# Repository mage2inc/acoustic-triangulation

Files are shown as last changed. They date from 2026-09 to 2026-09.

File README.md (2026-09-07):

# 🔊 acoustic-triangulation

> **DIY ShotSpotter for your property.** GPS-synchronized microphone nodes triangulate loud transients (gunshots, backfires, whatever goes boom) and pin the source on a map — no cloud, no subscription, ~$230 in parts.

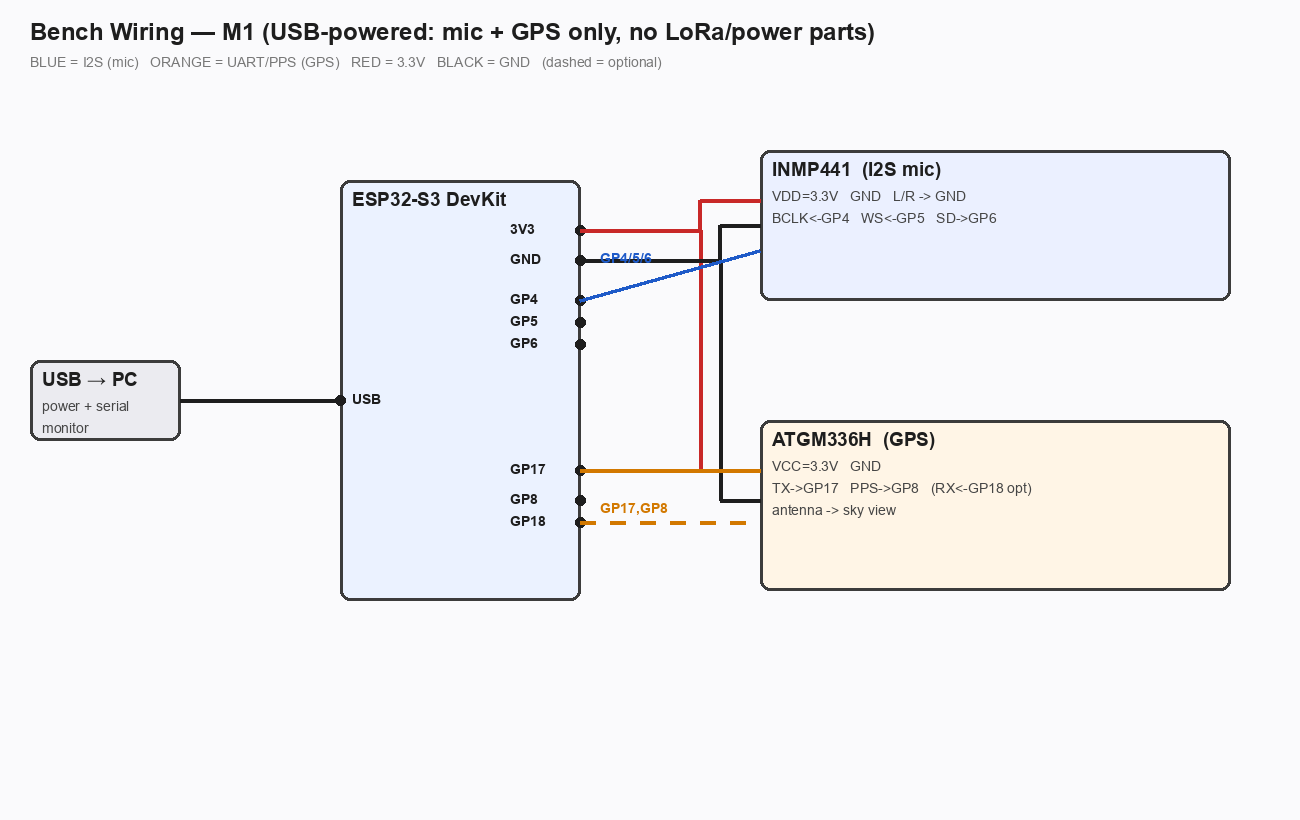
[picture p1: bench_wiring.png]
bench wiring


---

## How it works

Four solar-powered sensor nodes sit at the corners of the property. A fifth node lives indoors, doubles as the LoRa gateway, and feeds a Raspberry Pi.

When something loud happens, every node that hears it records the exact microsecond of arrival — disciplined to GPS PPS (the 1-pulse-per-second signal), which gives all nodes a common timebase accurate to <1 µs for free. Each node fires off a tiny 20-byte LoRa packet:

```
{ node_id, lat, lon, onset_time_µs, amplitude, classification }
```

The Pi collects the packets, computes **Time Difference of Arrival (TDoA)** across the nodes, and solves for the source location. Result: a dot on a Leaflet/OpenStreetMap web map, updated in real time.

**Expected accuracy:** 5–15 m. Dominated by GPS position error and node geometry, not timing.

---

## Why GPS PPS and not NTP / LoRa timing?

Sound travels ~34 cm per millisecond. NTP is good to ~10 ms → **3.4 m of timing error per ms**. LoRa is even slower and jittery. GPS PPS is <1 µs → sub-centimeter timing contribution. It's the only viable approach for outdoor acoustic TDoA at this scale.

LoRa is used **only** to ship the tiny detection report after the fact. It has nothing to do with timing.

---

## Hardware variants

Two board variants exist. **Only v2 has been built and tested on the bench.**

| Variant | Radio | PCB | Status |
|---|---|---|---|
| **v2 — RYLR689** | LLCC68 (SPI bare module) | Hand-wired breadboard / CNC milled | ✅ Tested — bench sync confirmed |
| **v3 — XL1276-P01** | SX1276 (SPI castellation) | JLCPCB 2-layer FR4, 56×53 mm | ⚠️ **UNTESTED** — gerbers ready, not yet ordered |

v3 uses the same ESP32-S3-Zero and GPS/mic modules as v2. The SX1276 needs 3 fewer GPIO pins (no BUSY, no RF-switch lines) and is meant to be manufactured, not hand-wired.

> **If you're building now, use v2 (RYLR689).** See [BOM.md](BOM.md) and [WIRING.md](WIRING.md).
> v3 PCB files and BOM are in this repo but have not been ordered or soldered yet.

---

### v2 field node ×4 (RYLR689 — active variant)

| Part | ~$ |
|---|---|
| ESP32-S3-Zero (dual-core LX7, 2 MB PSRAM) | 4.50 |
| INMP441 I²S MEMS microphone | 1.80 |
| RYLR689 LLCC68 915 MHz LoRa (SPI) | 9.00 |
| ATGM336H GPS with PPS pin | 4.50 |
| 6 V / 5 W solar panel | 8.00 |
| CN3791 MPPT solar charger | 3.00 |
| 18650 Li-ion cell + holder | 5.00 |
| IP65 ABS enclosure | 4.50 |
| Acoustic vent (PTFE membrane) | 1.50 |
| Misc wire / JST / mount | 5.00 |
| **Per node** | **~$47** |

### Office node ×1 (mains, USB-powered from Pi)

Same sensor stack, no solar/battery. Active external GPS antenna for indoor sky-view. Also acts as the LoRa gateway.

### Base station

Raspberry Pi (any model with USB) + the office node + a browser. No cloud. No API key. Leaflet + OpenStreetMap.

**Full BOM with sourcing notes and buy links → [BOM.md](BOM.md)**

**v3 (SX1276 / manufactured PCB) BOM and fab guide → [BOM_sx1276.md](BOM_sx1276.md) · [pcb/fab_guide_sx1276.md](pcb/fab_guide_sx1276.md)**

**Detailed power budget, solar sizing, and low-power DS3231 holdover variant → [POWER.md](POWER.md)**

---

## Repo layout

```
firmware/          PlatformIO project — ESP32-S3 node firmware
  src/
    acoustic_core.h   timing engine (GPS-PPS + I²S DMA ring + onset detector)
    node_config.h     pin map + node ID (edit per node)
    main_stageN.cpp   staged build environments (mic → GPS → onset → full node)
  platformio.ini      default env = SX1276; add -D LORA_MOD_LLCC68 for RYLR689

base/
  base_station.py   LoRa RX → TDoA solver → Leaflet map (Flask)
  test_solver.py    unit tests for the multilateration math
  requirements.txt

pcb/                       ⚠️ v3 SX1276 PCB — UNTESTED, not yet ordered
  gen_pcb_sx1276.py        Gerber generator (Python, no KiCad needed)
  gen_pcb.py               v2.2 RYLR689 CNC preview (reference only)
  out_sx1276/              Ready-to-upload gerbers for JLCPCB
  fab_guide_sx1276.md      JLCPCB ordering steps + pricing

BOM.md             v2 RYLR689 bill of materials (tested)
BOM_sx1276.md      v3 SX1276 bill of materials ⚠️ untested
POWER.md           Power budget, solar sizing, battery autonomy, DS3231 holdover
WIRING.md          Pin-by-pin wiring for both variants
POC.md             Proof-of-concept plan (USB-powered bench test first)
NODE_FIRMWARE_DESIGN.md  Detailed firmware architecture
FIELD_TEST.md      Field deployment checklist
```

---

## Firmware quick-start

Requires **PlatformIO** and the **pioarduino** platform (Arduino core 3.x — the new `i2s_std.h` driver needs it; stock espressif32 core 2.x won't compile).

```bash
cd firmware

# Stage 1 — mic level meter (sanity check before wiring everything)
pio run -e stage1 -t upload -t monitor

# Stage 2 — GPS lock + PPS pulse counter
pio run -e stage2 -t upload -t monitor

# Stage 3 — onset detection + PPS timestamp
pio run -e stage3 -t upload -t monitor

# Stage 4 — full node (onset → LoRa TX)
pio run -e stage4 -t upload -t monitor

# Stage 5 — base RX + sync check (run on office node / DevKit)
pio run -e stage5 -t upload -t monitor
```

Edit `src/node_config.h` to set `NODE_ID` (0–4) and verify pin assignments before flashing each node.

> **Gotcha:** the S3FH4R2 chip has 4 MB flash but the default board profile assumes 8 MB → bootloop. `platformio.ini` already sets `board_upload.flash_size=4MB` and `board_build.flash_size=4MB`. Don't remove those lines.

---

## Base station quick-start

```bash
cd base
pip install -r requirements.txt

# Sanity-check the solver math (runs without hardware)
python test_solver.py

# Start the gateway + map server
# Office node must be plugged in via USB
python base_station.py --port /dev/ttyUSB0 --map-port 5000
```

Open `http://localhost:5000` — events appear as pins on the map as they arrive.

---

## Node placement

Property is ~52 m × 155 m (long and narrow). **Do not line nodes along the centerline** — colinear geometry kills cross-width accuracy. Stagger them in a zigzag/W pattern, pushing to the extreme corners, so you get perpendicular baselines in both axes.

```
N1 ──────────────────── N2
 \                      /
  \    (office node)   /
   N5                 /
  /                  /
N3 ──────────────────── N4
```

Every node hears every event on this lot → over-determined system → ambiguity rejection works.

---

## Accuracy

| Error source | Contribution |
|---|---|
| GPS PPS timing | <1 µs → <0.3 mm |
| GPS position error (single-point) | ~2–5 m |
| Node geometry (52 m narrow axis) | limits cross-width to a few meters |
| Speed of sound variation (temp/wind) | ~1–3 m in practice |
| **Combined** | **~5–15 m** |

The timing is not the limiter. Node position error and geometry are. Sub-meter accuracy requires tape-survey + hardcoded positions.

---

## Cost

| Group | Cost |
|---|---|
| 4 solar field nodes | ~$189 |
| 1 mains office node | ~$28 |
| Base (Pi on hand) + microSD | ~$6 |
| Bench dev kit | ~$8 |
| **Total** | **~$231** |

Commercial ShotSpotter: $50,000–$100,000 per square mile. Just saying.

---

## License

MIT

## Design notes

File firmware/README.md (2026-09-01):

# Node firmware

ESP32-S3 node firmware for the acoustic triangulation array, built in testable
stages (see `../POC.md` for the milestone plan). Arduino framework via
**PlatformIO**.

## Toolchain
- Install PlatformIO (VS Code extension or `pip install platformio`).
- Board target: `esp32-s3-devkitc-1` (works for the DevKitC-1 *and* the
  ESP32-S3-Zero — same chip). Serial is native USB (CDC).

## Build & flash one stage
```
pio run -e stage1 -t upload -t monitor      # I2S mic level meter
pio run -e stage2 -t upload -t monitor      # GPS + PPS timestamp
```
(Each stage is one file selected by `build_src_filter` in `platformio.ini`.)

## Stages
| Stage | File | Proves | Pass criteria |
|---|---|---|---|
| 1 | `stage1_i2s_mic.cpp` | mic captures audio | tap/clap moves the RMS bar |
| 2 | `stage2_gps_pps.cpp` | PPS disciplines a µs clock | `interval` ≈ **1000000 µs** after fix |
| 3 | *(next)* | onset → GPS-time timestamp | clap prints a precise UTC-referenced µs |
| 4 | *(next)* | LoRa report | base prints the packet |
| 5 | *(next)* | **2-node PPS sync (M2)** | Δt ≈ Δdistance ÷ 343 m/s |
| 6 | *(Pi)* | multilaterate + Leaflet map | dot lands within a few m |

## Pin map
All pins in `src/node_config.h`. Set `NODE_ID` per node (1..5).

## Notes
- **Stage 2 needs sky view** — first GPS fix can take minutes; PPS typically
  starts after the first fix.
- If Stage 1 reads flat/zero: check `L/R`→GND and the SD/BCLK/WS wiring; the
  INMP441 drives the LEFT slot.
- Libs (`RadioLib`, `TinyGPSPlus`) auto-install on first build.

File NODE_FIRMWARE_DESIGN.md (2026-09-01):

# Acoustic Triangulation — Node Firmware Design

Two-tier (lazy) firmware for a solar-powered sensor node in a distributed
loud-noise/gunshot triangulation network. Nodes detect a loud transient,
precisely timestamp its **onset** against GPS PPS, classify it, and send a tiny
report over LoRa. The base station collects reports from ≥3 nodes and solves
for the source location (TDoA multilateration) on a Leaflet/OSM map.

**Design targets**
- Sub-meter localization on a 52 m × 155 m property.
- Runs continuously on solar; average current near the low-power floor.
- Rejects false alarms (thunder, car doors, dogs) via classification.

---

## 1. Hardware per node

| Block | Part | Interface | Notes |
|---|---|---|---|
| MCU | ESP32-S3 (N16R8, 16 MB flash / 8 MB PSRAM) | — | dual-core; wake-to-classify |
| Mic | INMP441 (I²S MEMS) | I²S | continuous DMA capture |
| Radio | Ra-01 / SX1278 (433 MHz LoRa) | SPI + DIO0 IRQ | tiny report packets |
| Time/pos | ATGM336H (GPS+BDS timing) | UART (NMEA) + **PPS** | PPS is the whole ballgame |
| Power | 5–6 W panel + 2× 18650 + CN3791/TP4056 | — | see power notes |

### Pin map — Waveshare ESP32-S3-Zero (final)
Board breaks out ~24 GPIO (GP1–18, 38–42, 45). Map avoids strapping pins
(0/3/45/46), USB console (43/44 = UART0), USB D±(19/20), and GP21 (onboard WS2812).
All signals are 3.3 V — no level shifting.
```
INMP441 (I²S):   BCLK=GP4    WS=GP5     SD=GP6         (L/R -> GND = left channel)
SX1278 (SPI):    SCK=GP12    MISO=GP13  MOSI=GP11
                 CS=GP10     RST=GP14   DIO0=GP9 (IRQ)
ATGM336H:        GPS_TX->GP17 (ESP RX)  ESP_TX->GP18 (GPS RX, optional)
                 PPS=GP8     (interrupt-capable, non-strapping — CRITICAL)
Status LED:      GP21 (onboard WS2812, no header pin)
Free for later:  GP1-3, 7, 15, 16, 38-42, 45  (SD logging, 2nd mic, PIR, ...)
```
Power: Ra-01 and ATGM336H on **3V3** (Ra-01 is NOT 5 V tolerant); board 5V pad
feeds the regulator from the solar/battery supply.

---

## 2. The crux: GPS-PPS timekeeping

Everything depends on all nodes sharing one clock to < ~1 ms. We get that from
the GPS **PPS** (pulse-per-second) edge, which is aligned across all GPS
receivers on Earth to < 1 µs. We never use LoRa for timing.

### Clock model
Maintain a mapping between the **local high-res timer** (`esp_timer`, 1 µs, or the
CPU cycle counter) and **GPS UTC**:

- On every **PPS rising edge** (hardware ISR), latch the local timer:
  `t_pps_local = now_us()`. The NMEA sentence that follows tells you which UTC
  second that PPS marked → keep `utc_at_pps`.
- Measure `ticks_between_pps = t_pps_local[n] - t_pps_local[n-1]`. Nominal is
  1 000 000 µs; the deviation is your local oscillator error (ppm). Use it to
  scale interpolation (optional but improves accuracy / holdover).

### Sample → GPS time
I²S samples arrive via DMA at a fixed rate `Fs` (e.g., 16 kHz). To timestamp a
specific **sample index**:

- On each DMA "buffer complete" ISR, latch `now_us()` and the running
  `sample_count`. This anchors `sample_index ↔ local_time`.
- For any sample: `local_time = anchor_time + (sample_index - anchor_index)/Fs`.
- Then convert local_time → GPS time via the PPS mapping:
  `T_gps = utc_at_pps + (local_time - t_pps_local) * (1e6 / ticks_between_pps)`.

**Achievable precision:** limited by `Fs` (16 kHz = 62.5 µs/sample; interpolate
the threshold crossing for sub-sample), ISR jitter (~µs), and PPS jitter (~µs).
Realistically **~50–200 µs → ~2–7 cm of ranging error**. Timing is *not* your
accuracy limiter; node geometry and echoes are.

> Keep the I²S DMA ring buffer running even in the low-power tier, so the
> onset sample already exists in memory when the threshold trips.

---

## 3. Audio ring buffer

A continuous circular buffer of recent audio in RAM.

- 16 kHz × 16-bit × 1.0 s = **32 KB** (trivial; with PSRAM keep several seconds).
- Purpose: **pre-trigger history.** The energy threshold trips slightly *after*
  the true onset; the pre-roll lets you look back and find the real onset edge.
- Window captured per event: ~50 ms pre-trigger + ~250 ms post-trigger.

```
      ring buffer (circular, always filling via DMA)
  ...[....pre-roll....][ONSET][....decay....].... write ptr ->
                         ^ found by looking back from trigger point
```

---

## 4. Two-tier state machine (the "lazy" design)

```
        ┌──────────────────────────────────────────────┐
        │  STATE_LISTEN  (CPU 80 MHz, low power)         │
        │  • I²S DMA -> ring buffer (always)             │
        │  • PPS ISR keeps clock disciplined             │
        │  • per-DMA-buffer: cheap energy/peak check     │
        │  • LoRa idle (sleep or RX)                     │
        └───────────────┬──────────────────────────────┘
                        │ energy > THRESHOLD
                        v
        ┌──────────────────────────────────────────────┐
        │  STATE_EVENT   (CPU 240 MHz, brief burst)      │
        │  1. snapshot ring-buffer window                │
        │  2. find precise onset sample (rising edge)    │
        │  3. T_onset = sample->GPS time  (Sec.2)        │
        │  4. classify window (Sec.5)                    │
        │  5. if of-interest: build + TX LoRa report     │
        │  6. refractory dead-time (~700 ms) to ignore   │
        │     echoes, then -> STATE_LISTEN               │
        └──────────────────────────────────────────────┘
```

Because loud events are rare (seconds/day), you sit in STATE_LISTEN ~99.9 % of
the time → average current ≈ the low tier, while STATE_EVENT gives you full
S3-class classification only when it matters.

> **Power reality:** this shaves the *CPU* portion. GPS (~30–50 mA continuous)
> is the dominant draw and is unchanged — it sets the floor.

---

## 5. Onset detection & classification

### Onset (timing-critical)
- Trigger: short-window RMS/energy over a sliding ~2–5 ms window exceeds an
  adaptive threshold (threshold = k × rolling noise floor).
- Precise onset: from the trigger point, walk **backward** in the ring buffer to
  the last sample below a lower fraction of the peak → that's the onset edge.
  Optionally linear-interpolate the exact crossing for sub-sample time.

### Classification (false-alarm rejection)
Compute cheap features over the captured window and score impulsive-vs-not:

| Feature | Gunshot-like | Rejects |
|---|---|---|
| Rise time (10→90 % of peak) | very short (< 1–2 ms) | slow → thunder, engine |
| Total duration | short (tens of ms + echoes) | long → rumble, music |
| Peak amplitude | high | low → distant/ambient |
| Spectral flatness / centroid | broadband, high | tonal → alarms, voices |
| Zero-crossing rate | high | low → thuds |
| (optional) crest factor | high | compressed sounds |

Start with a simple weighted-threshold rule; upgrade to a tiny TinyML model
later if needed. Emit a `class` id + `confidence`.

---

## 6. LoRa transmit — collision avoidance (important)

Every node hears the same gunshot within ~450 ms, so **all nodes want to
transmit at nearly the same instant** → LoRa collisions that could wipe out the
event. Two rules fix this:

1. **The timestamp is in the payload, not the RX time** — so *when* the packet
   arrives at the base doesn't matter. We can freely delay/jitter TX.
2. **Per-node staggered backoff:** after capturing `T_onset`, wait
   `backoff = node_id × 60 ms + small_random` before transmitting. Nodes'
   packets are then spread out and don't collide. Optionally listen-before-talk.

Also: 2–3 quick repeats per report (LoRa is lossy), deduped at the base by
`(node_id, seq)`.

### Packet format (~20 bytes — MOBILE nodes send their own position)
```
byte  field
0     node_id                (1)
1-2   seq                    (2)   for dedupe / repeats
3-7   onset_time_us          (5)   40-bit: µs-of-hour (or since GPS epoch tick)
8-11  latitude               (4)   int32, 1e-7 deg  (~1 cm resolution)
12-15 longitude              (4)   int32, 1e-7 deg
16-17 peak_amp               (2)
18    class_id               (1)
19    confidence             (1)
+ LoRa hardware CRC
```
> **Nodes are static during operation but self-locating.** At deploy each node
> takes a GPS position lock and **averages it while stationary** (pulls error to
> ~1–2 m), stores it, and includes it in every report. So nodes are plug-and-play
> and handle redeployment automatically — no manual survey, no base lookup table.
> GPS keeps running afterward purely for PPS timing.

**LoRa params:** 433 MHz, SF7–SF9 / 125 kHz (short range, low airtime), CRC on,
explicit header.

---

## 7. Concurrency layout (dual-core)

```
Core 0 (real-time, never blocks):
  • I²S DMA buffer-done ISR: latch time anchor, run energy check,
    set event flag on trigger
  • PPS ISR: latch t_pps_local, update clock mapping

Core 1 (app):
  • GPS UART / NMEA parse -> utc_at_pps, node health
  • on event flag: snapshot window, onset, classify, backoff, LoRa TX
  • status LED / housekeeping
```

Keep ISRs tiny (latch + flag). Do all heavy work (classify, TX) on Core 1.

---

## 8. Main-loop pseudocode

```c
void setup() {
  clock_set(80_MHz);
  i2s_start_dma(Fs=16000, ring_buffer);      // runs forever
  attach_isr(PPS_PIN, on_pps_edge);          // Core 0
  attach_i2s_done_isr(on_dma_buffer);        // Core 0
  gps_uart_begin();                          // Core 1
  lora_begin(433E6, SF8, 125E3);
  state = LISTEN;
}

// ---- Core 0 ISRs ----
void on_pps_edge() {
  uint64_t t = now_us();
  ticks_between_pps = t - t_pps_local;
  t_pps_local = t;
  pps_seen = true;                            // NMEA parser fills utc_at_pps
}

void on_dma_buffer(int16_t* buf, int n) {
  anchor_time = now_us(); anchor_index = (sample_count += n);
  float e = energy(buf, n);
  noise_floor = 0.999f*noise_floor + 0.001f*e;    // slow adaptive
  if (state == LISTEN && e > K * noise_floor) {
    trigger_index = sample_count;
    event_flag = true;                            // hand to Core 1
  }
}

// ---- Core 1 ----
void loop() {
  gps_service();                              // parse NMEA -> utc_at_pps
  if (event_flag && state == LISTEN) {
    state = EVENT; clock_set(240_MHz);
    Window w = snapshot_ring(trigger_index, PRE=50ms, POST=250ms);
    size_t onset = find_onset(w);
    uint64_t T_onset = sample_to_gps_time(onset);   // Sec.2
    Class c = classify(w);                          // Sec.5
    if (c.of_interest) {
      delay(node_id*60 + rand()%40);                // Sec.6 backoff
      lora_send(pack(node_id, seq++, T_onset, w.peak, c));
    }
    delay(REFRACTORY_700ms);                        // ignore echoes
    clock_set(80_MHz); state = LISTEN; event_flag = false;
  }
}
```

---

## 9. Base station (outline — separate doc later)

Runs on a Raspberry Pi + one Ra-01 gateway.

1. **Ingest**: receive LoRa reports, dedupe `(node_id, seq)`.
2. **Correlate**: group reports whose `onset_time_us` fall within ~450 ms
   (max propagation across the property) into one *event*.
3. **Solve**: TDoA multilateration using the **GPS-averaged node positions each
   node self-reports** + onset times. Least-squares / Levenberg–Marquardt seeded
   by a coarse grid search; output lat/lon + residual. Need ≥3 nodes; 4+ rejects
   the mirror ambiguity. Accuracy bounded by node position error: ~**2–5 m** with
   GPS averaging (or sub-meter if you also tape-survey and hardcode positions).
4. **Serve**: Leaflet + OpenStreetMap web page (WebSocket live) showing nodes,
   the computed source, and an error circle. Log every event to SQLite.

---

## 10. Tuning knobs & open items

- **Fs**: 16 kHz is plenty for onset timing + basic classify; 8 kHz saves power,
  32 kHz sharpens timing. Trade against CPU/power.
- **K (threshold)** and **noise-floor time constant**: field-tune to your
  ambient; too low = constant wakes (burns the lazy savings), too high = misses.
- **Refractory time**: long enough to swallow echoes off house/trees, short
  enough not to miss a real second event.
- **Node survey**: measure each node's lat/lon once (tape-measure to a local
  grid, or average a GPS fix for minutes). Store in the base's table. This is
  what turns ~3 m GPS error into cm-level position → sub-meter fixes.
- **Node layout**: stagger across the 52 m width; never colinear.
- **Power**: verify average current on the bench, then size panel/battery for
  worst-case cloudy days (target ≥2–3 days autonomy). GPS is the floor —
  consider GPS duty-cycling + a TCXO holdover only if you must go lower.
- **LoRa duty cycle / region**: mind 433 MHz regional limits; reports are tiny
  so this is easy to stay under.

---

---

## Appendix A — Low-Power Variant (GPS duty-cycle + DS3231 holdover)

**Optional.** The default design runs GPS continuously (~30 mA = half the node
budget). This variant nearly halves node draw for nodes that need it. **Skip it
for solar nodes** (already power-positive); use it only for:
- battery-only nodes (no solar) — halving draw ~doubles runtime,
- heavily shaded sites where the 5 W panel can't keep up,
- shrinking to a smaller panel/battery to cut cost/size.

### Idea
A bare ESP32 crystal drifts too fast — and drifts with *outdoor temperature* —
so you can't coast without GPS. Add a **DS3231 (TCXO RTC, ±2 ppm, temperature-
stable)**. Then you can turn the GPS OFF and hold time on the TCXO between brief
re-syncs.

### Added hardware
- **DS3231 + AT24C32 module** (~$2, I²C). TCXO holdover + EEPROM for node
  config/ID/optional surveyed position.
- **High-side P-MOSFET** (or the GPS module's standby pin) to gate GPS power.

### Extra pins (from the free set)
```
DS3231 I²C:   SDA=GP1   SCL=GP2
DS3231 32kHz: 32K -> GP7   (optional: TCXO reference into a counter)
GPS enable:   GP15 -> MOSFET gate (cut GPS VCC when sleeping)
```

### How it works
1. **Sync phase (GPS on):** get position fix (average once, store in EEPROM) +
   discipline the ESP32 high-res timer against PPS; measure the TCXO's exact
   offset. Establish `timer_ticks ↔ GPS_time` and the ppm correction.
2. **Holdover phase (GPS off):** run the ESP32 fast timer, corrected by the
   DS3231 32.768 kHz TCXO reference (temperature-stable). Onset timestamps use
   this held timebase. Coast for the re-sync interval.
3. **Re-sync:** every ~2–3 min pulse GPS on (~2 s hot-start), re-lock PPS,
   re-measure the timer offset, GPS off again.

### Budget & timing
- GPS: ~30 mA continuous → **~1 mA average** (~1.6 % duty) + ~0.2 mA DS3231.
- **Node ~58 mA → ~28 mA** (roughly halved).
- Timing: ±2 ppm over a 3-min holdover → worst-case ~0.7 ms cross-node relative
  drift → **~0.25 m ranging error** — inside the 2–5 m target. Tighten the
  re-sync interval if you want margin.

### Cost / risk
Real firmware complexity: holdover discipline math, GPS on/off sequencing, and
you MUST field-validate cross-node timing holds (compare a known common event).
Not worth it unless power-starved. Keep the DS3231 as a stocked option.

---

*Status: design. Next: exact BOM w/ links, then implement node firmware
(I²S + PPS timestamp first, then classify, then LoRa), then the base solver+map.*

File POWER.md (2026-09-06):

# Power Budget — Acoustic Triangulation Nodes

## Field node current draw (continuous, 3.3 V rail)

| Subsystem | Mode | Current |
|---|---|---|
| ESP32-S3 (dual-core @ 80 MHz, STATE_LISTEN) | always-on | ~25 mA |
| ATGM336H GPS (lock acquired, PPS running) | always-on | ~28–35 mA |
| INMP441 MEMS mic (I²S DMA, always capturing) | always-on | ~1.4 mA |
| RYLR689 LoRa (idle / Tx burst avg ~0.1% duty) | mostly sleep | ~1–2 mA |
| **Total (typical)** | | **~58 mA** |

> **GPS is the dominant draw** — it stays on 100% of the time because it provides
> both the position AND the PPS timebase. Duty-cycling it saves ~15 mA average
> but requires a DS3231 TCXO holdover and adds firmware complexity (see Appendix A).

During `STATE_EVENT` (onset detected, classify + LoRa Tx):
- CPU briefly runs @ 240 MHz → +~50 mA for ~100–300 ms
- LoRa Tx @ +20 dBm → +~120 mA for ~50 ms
- Both are short bursts; average impact on daily energy is negligible (<0.5%)

**Average draw used for sizing: 58 mA @ 3.3 V = ~0.19 W**

---

## Daily energy

```
58 mA × 3.3 V × 24 h = 4.6 Wh/day
```

---

## Solar panel sizing

A 5 W / 6 V panel in a mid-latitude location with ~4 peak-sun-hours/day delivers:

```
5 W × 4 h × ~0.85 (MPPT efficiency) = ~17 Wh/day harvested
```

vs. **4.6 Wh/day needed** → **3.7× margin**. Covers cloudy stretches and charging
the battery simultaneously. Don't downsize the panel — the GPS is not negotiable.

| Panel | Cost | Verdict |
|---|---|---|
| 6 V 5 W (110 × 136 mm) | ~$8 | ✅ right-sized, use this |
| 6 V 2 W | ~$4 | ❌ marginal even in full sun |
| 12 V 10 W | ~$15 | overkill, also needs a different charger |

> **"10 W" panel gotcha:** a panel labeled 10 W doing 12 V × 0.166 A is really
> ~2 W. Always check Vop × Iop (the operating point), not the label.

---

## Battery sizing

| Config | Capacity | Autonomy (no sun) | Notes |
|---|---|---|---|
| 1× 18650 (2 500 mAh) | ~8.3 Wh | **~1.5 days** | lean / default BOM |
| 2× 18650 (5 000 mAh) | ~16.5 Wh | **~3.5 days** | +$4/node, recommended |
| 3× 18650 (7 500 mAh) | ~24.8 Wh | **~5 days** | +$8/node, comfortable margin |
| 1× 32700 LiFePO₄ (6 000 mAh) | ~19.8 Wh | **~4.2 days** | +$5/node, safer in hot enclosures |

Autonomy formula: `capacity_Wh / 4.6 Wh/day`

**Recommendation:** 2× 18650 in parallel (or 1× 32700 LiFePO₄ if the enclosure
gets hot). The system tolerates a node browning out and rejoining — a missed
detection just reduces fix quality slightly.

> ❌ **Never use a USB power bank.** They auto-cutoff at low draw (~58 mA triggers
> most power banks' "no load" protection). Use bare Li-ion cells with a 1S
> protection board, or protected cells.

---

## Power chain

```
6 V solar panel
    │
    ▼
CN3791 MPPT charger  ──── charges ──── 18650 cell (1S)
    │                                       │
    └─── (direct path when sun > load) ─────┘
                                            │
                                        Schottky diode
                                            │
                                    ESP32-S3-Zero 5V pad
                                            │
                                     onboard AMS1117 LDO
                                            │
                                           3V3 ──► GPS, mic, LoRa, ESP32
```

No separate buck-boost needed — the ESP32-S3-Zero's onboard LDO accepts 3.3–6 V
on the 5V pad and regulates to 3.3 V. The Schottky diode prevents USB-C and the
solar supply from fighting when you plug in for debugging.

---

## Appendix A: Low-power variant (DS3231 holdover)

Halves average current by duty-cycling the GPS. Only worthwhile on battery-only
or heavily shaded nodes.

### How it works

1. Node acquires GPS lock, pairs PPS, then gates off the GPS module.
2. A DS3231 TCXO RTC (±2 ppm) takes over as the time reference.
3. GPS wakes every ~3 minutes for a 2–5 s re-discipline pulse, then sleeps again.

### Error budget during holdover

```
Holdover gap: 3 min = 180 s
DS3231 drift: ±2 ppm
Max timing error: 180 s × 2×10⁻⁶ = 360 µs
Distance error: 360 µs × 343 m/s = ~0.12 m
```

Sub-meter — GPS position error (2–5 m) still dominates. The holdover approach is
timing-safe.

### Power savings

| Subsystem | Always-on | With holdover |
|---|---|---|
| GPS | ~30 mA | ~2 mA avg (30 mA × 5 s / 180 s) |
| DS3231 | 0 | ~0.2 mA |
| **Total** | **~58 mA** | **~30 mA** |

~48% reduction. Daily energy drops from 4.6 Wh to ~2.4 Wh → a 2 W panel and
1× 18650 are sufficient.

### Cost

| Part | ~$ |
|---|---|
| DS3231 RTC module (32 kHz + coin cell backup) | $1.50 |
| CR2032 coin cell | $0.50 |
| **Per node add-on** | **~$2** |

### When to use it

- Battery-only nodes (no solar) ✅
- Heavily shaded nodes where the 5 W panel can't fully recharge ✅
- Nodes that need to last a week between maintenance visits ✅
- Solar nodes in a sunny location ❌ (already power-positive, not worth the complexity)

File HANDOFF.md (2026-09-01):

# HANDOFF — Acoustic Triangulation (portable/uConsole continuation)

Self-contained project. Read `PROJECT_MEMORY.md` first (full context), then
`POC.md` (plan) and `firmware/README.md` (build).

## Where we are (hardware bring-up, verified on a MacBook)
- Board CONFIRMED: ESP32-S3, 4MB flash / 2MB PSRAM (S3FH4R2). `/dev/cu.usbmodem2101` on the Mac.
- Toolchain: PlatformIO + **pioarduino platform** (core 3.x) — set in `firmware/platformio.ini`.
  Also fixed: **4MB flash override** (board_upload.flash_size=4MB, partitions=default.csv).
- Pin map moved to the GP1..13 breadboard header (this board's GP14+/GP17/18 are solder pads).
  See `firmware/src/node_config.h`: I2S 4/5/6, GPS TX->GP1 / PPS->GP8, LoRa 12/13/11/10/9/RST=7.
- Stage 1 (mic): PASS — RMS/peak jump with sound.
- Stage 2 (GPS): GPS UART WIRED OK (NMEA chars climbing). sats=0 INDOORS (no fix yet).

## NEXT STEP (needs sky view — that's why we're going portable)
1. Plug the ESP32 into the uConsole. `pip install platformio` if needed.
2. `cd firmware && pio run -e stage2 -t upload -t monitor`  (port may be /dev/ttyACM0)
3. Take it OUTSIDE / by a window. Wait for `sats` to climb, get a fix, then PPS starts:
   confirm **`interval` locks to ~1000000 us**. That proves PPS/GP8 + the synchronized clock.
4. Then `pio run -e stage3 -t upload -t monitor`, clap -> prints a GPS-referenced timestamp = **M1 DONE**.
5. M2 (make-or-break): 2 nodes on stage4 + a base on stage5, clap between them,
   verify base prints `dt ~ Δdistance/343`.

## Notes for the uConsole
- Serial port is likely /dev/ttyACM0 (not cu.usbmodem). Add `--upload-port /dev/ttyACM0` or set `upload_port`/`monitor_port` in platformio.ini.
- First `pio run` downloads the toolchain (~few min).
- Base solver already validated (base/test_solver.py: 0.04m clean, ~2.8m realistic).

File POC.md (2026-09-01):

# Proof-of-Concept Plan (USB-powered, no solar/battery)

Validate the *risky* parts — GPS-PPS time-sync and TDoA — before investing in
the power hardware. POC kits become the real nodes later (just add the power
stack). Nothing wasted.

## POC BOM (per node, USB-powered)
| Item | ~$ |
|---|---|
| ESP32-S3-Zero | 4.50 |
| INMP441 I²S mic | 1.80 |
| Ra-01 SX1278 w/ spring antenna | 4.50 |
| ATGM336H GPS (PPS + antenna) | 4.50 |
| USB-C cable | 1.50 |
| **Per node** | **~$17** |

**Dropped for POC:** solar panel, CN3791, 18650 + holder, Schottky/cap
(buck-boost already dropped), enclosure, acoustic vent.

**Power during test:** USB wall adapter + outdoor extension, or a power bank with
an always-on/low-current mode (plain power banks auto-off at ~58 mA). GPS needs
sky-view → nodes at windows / outside during tests.

## Cost
4 node kits (~$68) + ESP32-S3-DevKitC-1 (~$8) + Pi/microSD (on hand) ≈ **~$76**
vs ~$209 full build. Power hardware deferred until M2 passes.

## Milestones
1. **M1 — 1 node (bench).** I²S capture → onset detect → GPS lock → PPS timestamp
   → LoRa packet to base. Proves the node pipeline end to end. *(1 kit + DevKit)*
2. **M2 — 2 nodes (make-or-break).** Known separation; clap/bang; verify both
   timestamp the SAME event and Δt ≈ (Δdistance ÷ 343 m/s). **If PPS sync holds
   here, the project works.** *(2 kits)*
3. **M3 — 4 nodes at corners.** Full triangulation + Leaflet map; check fixes land
   within a few meters of the real source. *(4 kits)*

## After POC
Once M2/M3 pass, add per node: 12 V ~5–6 W panel + CN3791 (matched to panel V) +
3× 18650 (parallel) + Schottky + cap + IP65 box + acoustic vent. See BOM.md.

## Build order for firmware (do M1 first)
1. I²S continuous capture into a ring buffer (verify clean audio).
2. GPS NMEA parse + **PPS interrupt → discipline µs timer** (the crux).
3. Onset detect + sample→GPS-time timestamp.
4. LoRa packet {node_id, onset_us, lat, lon, amp} → base.
5. Base: collect, correlate, multilaterate, Leaflet map.

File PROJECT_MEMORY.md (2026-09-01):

---
name: project_acoustic_triangulation
description: Distributed loud-noise/gunshot TDoA triangulation network — MCU+mic+GPS+LoRa field nodes report to a base station that multilaterates and plots the source on a web map
metadata: 
  node_type: memory
  type: project
  originSessionId: 24c60d79-960e-49b6-99aa-ac79bfe38bc8
---

DIY ShotSpotter-style acoustic sensor network. Many field units (microcontroller + microphone + GPS + LoRa) detect loud transients, report to a base station over LoRa; base triangulates the source and plots it on a map with an API.

**Core method: TDoA multilateration.** Each node timestamps sound *arrival*; differences in arrival times × speed of sound (343 m/s) + known GPS node positions → solve for source. Need ≥3 nodes hearing an event for a 2D fix, 4+ for robustness/ambiguity rejection.

**THE make-or-break design point: time sync via GPS PPS, NOT LoRa.** Sound travels ~34 cm/ms; LoRa is far too slow/jittery for timing. Every node disciplines its µs clock to the GPS **PPS (pulse-per-second, <1µs)** signal → common timebase for free. LoRa is used ONLY to send a tiny detection report `{node_id, lat, lon, onset_time_µs, amplitude}` (~20 bytes) after a trigger — never for timing or audio.

**Hardware recommended:**
- Node: **LilyGO T-Beam** (ESP32 + NEO-M8N GPS + SX1262 LoRa + 18650 holder, all on one board) — add a mic, break out GPS PPS pin.
- Mic: I²C mic is a poor fit (slow sound-level sensor). Prefer **analog electret + comparator IRQ** (crispest onset timestamp) or **I²S MEMS (INMP441/ICS-43434)** for waveform + classification.
- Base: another T-Beam/Heltec as LoRa gateway + Raspberry Pi for the correlation/solver + web map.
- Map: Leaflet+OpenStreetMap (free, no key) default; Google Maps API optional (needs key + billing).

**Realistic accuracy:** ~5–15 m with PPS sync, dominated by GPS position error + node geometry (spread nodes, avoid colinear). Gunshots carry ~1–2 km → space nodes ~300–800 m so any point is heard by ≥3–4 nodes.

**Scope (fixed install):** 4–5 solar-powered nodes over user's ~2-acre property, which is LONG & NARROW: **170 × 510 ft = 52m × 155m**. Long axis 155m. CRITICAL placement note: do NOT line nodes along the centerline (colinear = poor cross-width fix) — STAGGER them left/right across the 52m width (zigzag/W pattern, push to extreme corners) to create perpendicular baselines. Along-length accuracy great (155m baseline); across-width limited by 52m baseline but still a few m. Every node still hears every event.

**Decisions locked:** map = Leaflet + OpenStreetMap (free, self-hosted on Pi); link = LoRa (nodes send tiny onset-timestamp reports).

**Topology (confirmed):** 5 sensors = 4 solar/battery field nodes (one at each corner of the ~52×155m lot) + 1 mains-powered OFFICE node (sensor + LoRa gateway + base, ~1/3 along the long axis, USB to Pi). All 5 hear every event → over-determined. Office needs GPS sky-view (active external antenna) for PPS. Battery = Li-ion 1S/parallel (site doesn't freeze); lean default 1×18650 (~1.5-day autonomy, system tolerates a node browning out & rejoining). ~5W panel is right-sized for continuous-GPS (~4.6Wh/day) — don't shrink it; save on battery instead, or mains-tap corners near power, or DS3231-holdover to halve draw. **Project ~$217** (lean, Pi on hand). BOM + firmware design: `~/Desktop/acoustic-triangulation/`.

**Node position model (confirmed):** nodes are STATIC during operation but SELF-LOCATING — at deploy each node takes a GPS lock and averages it while stationary (~1-2m), stores it, and includes its position in every report packet (~20B: node_id+seq+onset_us+lat+lon+amp+class). Same GPS then runs continuously for PPS timing. Plug-and-play / handles redeployment (they're repositionable between sessions, hence "non-stationary" — but fixed while listening). No manual survey or base lookup table needed. **Accuracy ~2-5m** with GPS averaging; sub-meter only if you also tape-survey + hardcode. GPS stays always-on (position + PPS) → ~30mA GPS ≈ half the node budget. Node power budget: ~58mA avg @3.3V (ESP32@80MHz ~25 + GPS ~30 + mic ~1.4 + LoRa sleep), ~4.6Wh/day, 5W panel covers it, 1×32700 ≈ 3-day autonomy. **Low-power variant (documented in design doc Appendix A):** add DS3231 (TCXO RTC ±2ppm) → duty-cycle GPS (on ~2s every ~3min, coast on TCXO holdover) → node ~58→~28mA (halved), ~0.25m timing error over 3min holdover — ONLY worth it for battery-only/shaded nodes; skip for solar (already power-positive).

**Solar power budget:** continuous mic listening + MCU + GPS ≈ 150–250mA average (GPS is the hog). Size ~5W panel + ≥5000mAh Li-ion (or small LiFePO4) + charge controller; a single 18650 won't survive night+cloudy. Optionally duty-cycle GPS (discipline TCXO via PPS, gate GPS) to cut power, but mic+MCU stay always-on.

**Small-property note:** LoRa still fine (low power, robust), but WiFi/ESP-NOW is an alternative at 90m range (already on ESP32, lower latency).

**Node firmware design doc:** `~/Desktop/acoustic-triangulation/NODE_FIRMWARE_DESIGN.md` — full two-tier (lazy) design: GPS-PPS timekeeping (sample-index→local-timer anchor→GPS via PPS mapping, ~50-200µs), always-on I²S DMA ring buffer w/ pre-trigger, STATE_LISTEN(80MHz energy check)→STATE_EVENT(240MHz classify+timestamp+TX)→refractory, classification features (rise-time/duration/spectral-flatness/ZCR), LoRa collision-avoidance via per-node staggered backoff (timestamp is IN payload so TX time doesn't matter), ~12B packet (node_id only — positions surveyed at base), dual-core layout, pseudocode, base-station outline. Recommended MCU: ESP32-S3 N16R8 (dual-core+PSRAM for wake-to-classify).

**MCU chosen:** ESP32-S3-Zero / SuperMini (ESP32-S3FH4R2: dual-core LX7 240MHz, 512KB SRAM, 4MB flash, **2MB PSRAM**, 24 GPIO, 2×I²S/4×SPI/3×UART, castellated, ~$3-5). 2MB PSRAM is plenty (audio buffer+classifier need <few hundred KB). Pin-map caveats: GPIO33-37 NOT broken out (PSRAM-reserved), GPIO21=onboard WS2812 LED, GPIO43/44=USB-serial console (put GPS UART elsewhere), GPIO19/20=native USB. ~20 usable pins, 12 needed → fits with planning. Castellated=solder-direct → get 1 headered DevKitC-1 for bench dev, build 5 field nodes on S3-Zeros.

**Approach:** POC FIRST (USB-powered, no solar/battery) to validate the risky parts (GPS-PPS sync + TDoA) before buying power hardware. POC kits = real nodes later (add power stack). POC plan in `~/Desktop/acoustic-triangulation/POC.md`: per-node ~$17 (S3-Zero+INMP441+Ra-01+ATGM336H+USB), ~$76 total for 4 kits+DevKit vs ~$209 full. Milestones: M1 1-node pipeline (I²S→onset→PPS-timestamp→LoRa), M2 2-node PPS-sync validation (THE make-or-break: Δt ≈ Δdist/343), M3 4-node triangulation+map. Fake-panel lesson: watts = Vop×Iop (a "10W" 110×136mm panel doing 12V×0.166A is really ~2W). Panel for real build: 12V ~5-6W matched to CN3791 set-point; 2-3× 18650 parallel (1S) — 3 cells ≈ ~6 days battery-only autonomy at ~58mA draw.

**FIRMWARE (2026-08-14): written, compile-verified, twice adversarially reviewed, math-validated.** In `~/Desktop/acoustic-triangulation/firmware/` (PlatformIO). CRITICAL toolchain note: MUST use **pioarduino platform** (Arduino core 3.x) not stock espressif32 (core 2.x) — the new `i2s_std.h` I2S driver needs 3.x. `platform = https://github.com/pioarduino/platform-espressif32/releases/download/stable/platform-espressif32.zip`. Board `esp32-s3-devkitc-1`. **2nd gotcha (fixed in platformio.ini): S3FH4R2 has only 4MB flash but the board profile assumes 8MB → bootloop "partition invalid exceeds flash chip size". Fix: `board_upload.flash_size=4MB`, `board_build.flash_size=4MB`, `board_build.partitions=default.csv`.** VERIFIED on real hardware 2026-08-28: chip = ESP32-S3 (QFN56 rev v0.2, 4MB flash/2MB PSRAM) on /dev/cu.usbmodem2101; stage1 compiles+uploads+boots+runs the level meter (reads 0 w/o mic). Build one stage: `pio run -e stageN -t upload -t monitor`. Stages: 1=mic level, 2=GPS/PPS, 3=onset+timestamp, 4=full LoRa node, 5=base RX+sync-check. Shared `acoustic_core.h` = the correct timing path: I2S DMA on_recv callback → ring buffer + seqlock time anchor (onset time tied to capture instant, not loop), backward-walk onset to 20% of peak, NMEA-triggered atomic PPS pairing w/ interval-health + staleness + stall-guard. Set NODE_ID per node in node_config.h (pins there too). Base in `~/Desktop/acoustic-triangulation/base/base_station.py` (serial→correlate→TDoA multilaterate→Leaflet map); `test_solver.py` VALIDATES math (0.04m clean, ~2.8m w/ 2.5m GPS pos error — timing is NOT limiter, node position is). Deps: numpy scipy pyserial flask.

**Key bugs caught pre-hardware (adversarial review):** (1) solver residuals were in seconds→least-squares quit without moving (40m err)→scale to METERS + grid-seed; (2) onset timestamp latched after blocking read→ms jitter that doesn't cancel across nodes→DMA-callback anchor; (3) onset localized only within one 8ms chunk, amplitude-dependent→ring+backward-walk; (4) PPS↔NMEA-second race→1s differential→NMEA-triggered atomic pairing+stall-guard. All fixed + recompiled clean.

**Status (2026-08-14):** firmware ready to flash on arrival; M1 = prove stage3 onset+PPS on bench, M2 = 2-node sync (stage4+5, the make-or-break). Bench-check: stage3 must print onsets (confirms callback-only I2S advances g_head). Remaining decisions: mic interface (analog-comparator vs I2S vs I2C), map platform (Leaflet/OSM vs Google), link (LoRa vs ESP-NOW). User has lots of Pi/SDR/RF gear (see [[reference_wardrive_rig]], [[project_uconsole_kali_install]]) and HackRF.

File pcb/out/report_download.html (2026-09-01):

Acoustic triangulation · node carrier

# PCB Inspection Packet

Everything for a design review before any copper is cut — placement, routed copper, and a 1:1 template you print at 100% to check that every part physically fits.

5656×50 mm#215;5356×50 mmnbsp;mm board 2-layer milled 0 copper crossings 2 jumper wires GND pour

Download node_report.pdf PDF · 4 pages · 400 KB

Before
milling

Print page 4 at 100% / “actual size” and caliper the red scale bar — it must read 50.0 mm. Then lay the real modules on the pads to confirm fit, and run a drill-only test cut before isolation routing.

Preview — node_report.pdfpages 1–4

generated from pcb/gen_pdf.py · self-contained, no external assets

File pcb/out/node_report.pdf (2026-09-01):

## ACOUSTIC NODE CARRIER — INSPECTION PACKET [v2.2]

2-layer CNC isolation-milled · 56 x 53 mm · unplated holes · GND pour (bottom)

### LAYER / ROUTING

RED | = top copper | (SPI bus, mic I2S, NRST, C1 decoupling AT LoRa VDD)
BLUE = bottom copper (3V3 rails + JP1 ferrite + threaded crossing, PPPS) + POUR
GRN | = 0 jumper wires! | BUSY = top->via->bottom copper; DIO1 = all bottom copper
0 copper crossings + 0 trace-over-pad shorts (machine-verified DRC).
3V3: LDO feeds mic/GPS with no crossing; JP1 ferrite, then ONE 0.3mm trace threads the ESP RX<->G1 gap. UNIFORM 0.47mm isolation floor everywhere (set by LoRa 1.27 pitch) -> constant-Z millable, NO height map needed. EDGE CUTS: cut the outline + USB-C plug notch (bottom) + coil-ant notch (top) RF KEEPOUT (v2): clear ALL bottom GND pour inside the magenta box at the ANT feed (ANT/ANT_PAD are the 50ohm RF output) -- do not backfill copper there.
BILL OF MATERIALS | (per node; blue rows are clickable -> Amazon)
U1 | ESP32-S3 SuperMini - soldered FLAT via castellations (not socketed) (https://www.amazon.com/dp/B0F6YJL9NM)
U2 | INMP441 I2S mic - O13.9 round, 2x3 @ 2.54, rows 7mm apart (https://www.amazon.com/dp/B09BB1F4C8)
U3 | ATGM336H GPS (1x5) - hangs off TOP edge | [confirm PPS pad on listing] (https://www.amazon.com/dp/B0DFYM7FPS)
U4 | REYAX RYLR689 LoRa (LLCC68 SPI, 915MHz, 1.27mm castellated), 2pk (https://www.amazon.com/dp/B0BNVKQ9JD)
U5 | MCP1700-3302E/TO LDO 3V3 TO-92 (1 GND|2 VIN|3 VOUT) | 2nd:HT7333-A (https://www.amazon.com/dp/B091C4NGTR)
C1 | 10uF 25V MLCC 0805 at LoRa VDD (top-mount, ties to LVDD/LGND) (https://www.amazon.com/dp/B07P77YXS7)
Cin | 1uF + 10uF 0805 MLCC assortment kit (Cin/Cout, 1uF each) (https://www.amazon.com/dp/B06XDG3WQX)
C2 | 470uF 10V/16V LOW-ESR electrolytic (Nichicon PM) = TX-spike buffer (https://www.amazon.com/dp/B00RH8DB40)
L1 | ferrite bead 0805 ~600ohm@100MHz (TDK MPZ2012S601) on JP1 3V3 crossing (https://www.amazon.com/dp/B0B8MN84RJ)
V1 | 1 via (BUSY). JP1=0805 via-in-pad: solder-bridge to rail; bridge pads=bypass
BAT | 18650 holder (2-wire) + your CN3791 charger -> BATT-IN pads (3.0-4.2V) (https://www.amazon.com/dp/B08Q399339)
HW | 4x M3 standoff/screw kit | + | 2-layer FR1/FR4 clad stock (https://www.amazon.com/dp/B01HDR72Q2)

2nd-source LDO: HT7333-A 20pk (TO-92, same pinout) (https://www.amazon.com/dp/B07KX5YL6Y)

L1 isolates ESP+LoRa HF noise from the mic/GPS supply (~20-40dB, 50-300MHz). It

does NOT fix TX droop (C2 does) or radiated GPS<->LoRa antenna coupling. Optional:

a solder bridge across the pads bypasses it (0-ohm) if it ever causes trouble.

NOTE: coin SUPERCAPS rejected -- 30-120ohm ESR drops 4-9V on the 120mA TX pulse;

a 470uF low-ESR e-cap (<0.1ohm) sources it flat.

NET MAP | (matches firmware node_config.h)
GP4 | Mic BCLK | GP5 | Mic WS | GP6 | Mic SD | (I2S, L/R->GND = left)
GP13 MISO | GP12 MOSI | GP11 SCK | GP10 NSS | (SPI, ESP right column)
GP8 | RFSW_V2 | GP9 | RFSW_V1 | (RF switch; each pin to its outer pad)
GP7 | BUSY (copper+via) | GP3 DIO1 (copper) | GP44 NRST (top)
GP1 | GPS TX(in) GP2 | GPS PPS | (GPS RX = no-connect)
3V3 -> mic/gps/lora VDD (C1 at LoRa VDD) | GND pour -> all grounds
>> HOW TO CHECK PARTS FIT | (before cutting copper) <<
1. Print PAGE 4 at 100% / "actual size" (NOT fit-to-page). Then caliper the 50 mm scale bar — it MUST read 50.0 mm. Re-print if off.
2. Set each real module on its pad group: pin pitch lands in the holes, the body outline (dashed) has clearance, antenna/USB edges point the right way.
3. Caliper-verify the footprints assumed vs your actual parts:
ESP SuperMini 2.54 pitch, rows 15.24, body 22.52x18
RYLR689 body 12.70x15.24, pads 1.27 pitch, rows 15.24 <- finest
ATGM336H 1x5 @ 2.54 | · | INMP441 Ø13.9 round, 2x3 @ 2.54, rows 7mm
4. DRILL-ONLY test cut on scrap; dry-fit ALL parts + standoffs; THEN mill.
5. Optional: mill one board first, populate + verify before making the 2nd.
pages: 2 = placement (assembly) | 3 = routed copper | 4 = 1:1 fit/drill template

## PAGE 2 — COMPONENT PLACEMENT (assembly, top view)

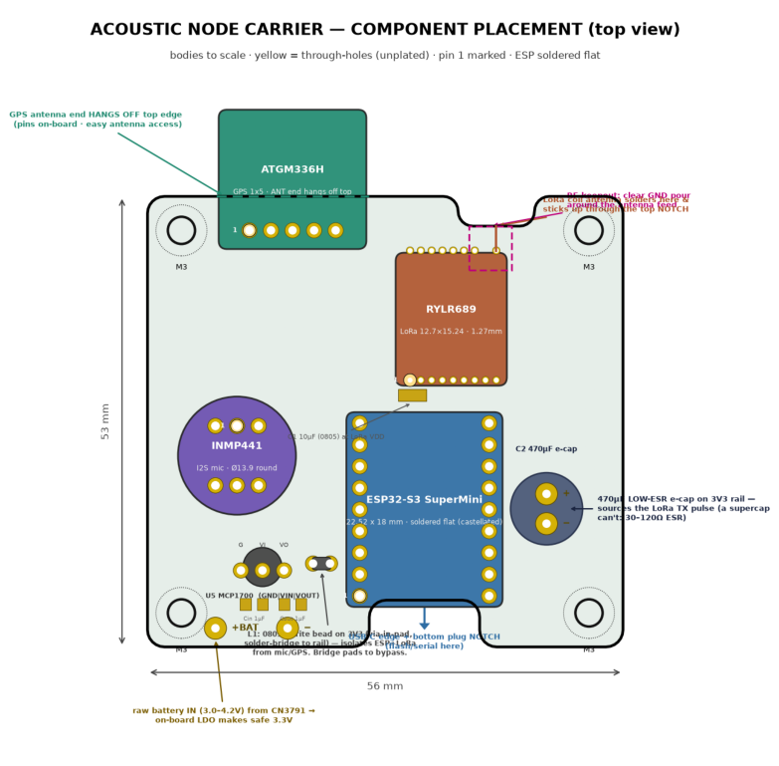
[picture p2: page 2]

## PAGE 3 — ROUTED COPPER (red=top, blue=bottom, green=jumper)

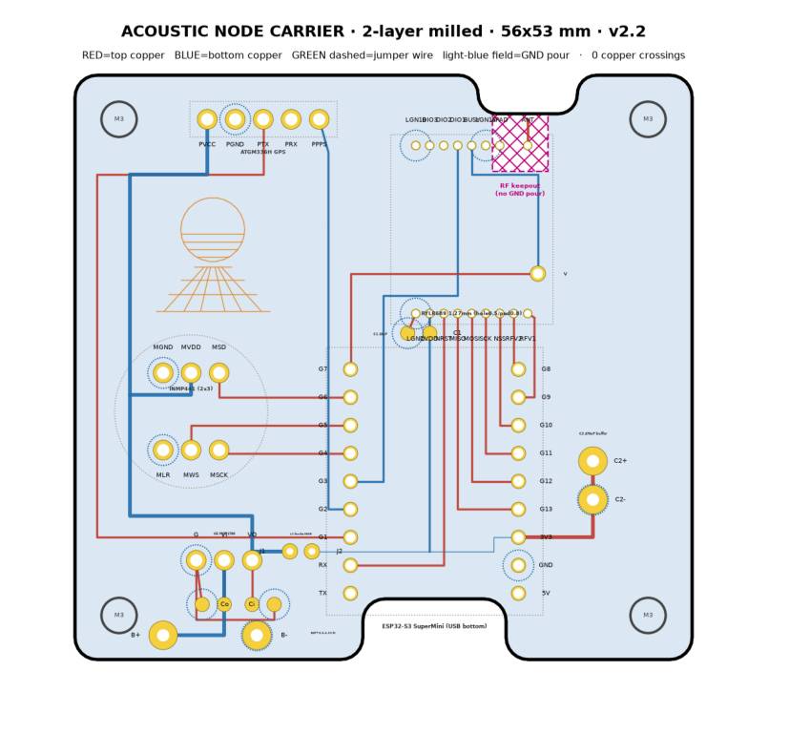
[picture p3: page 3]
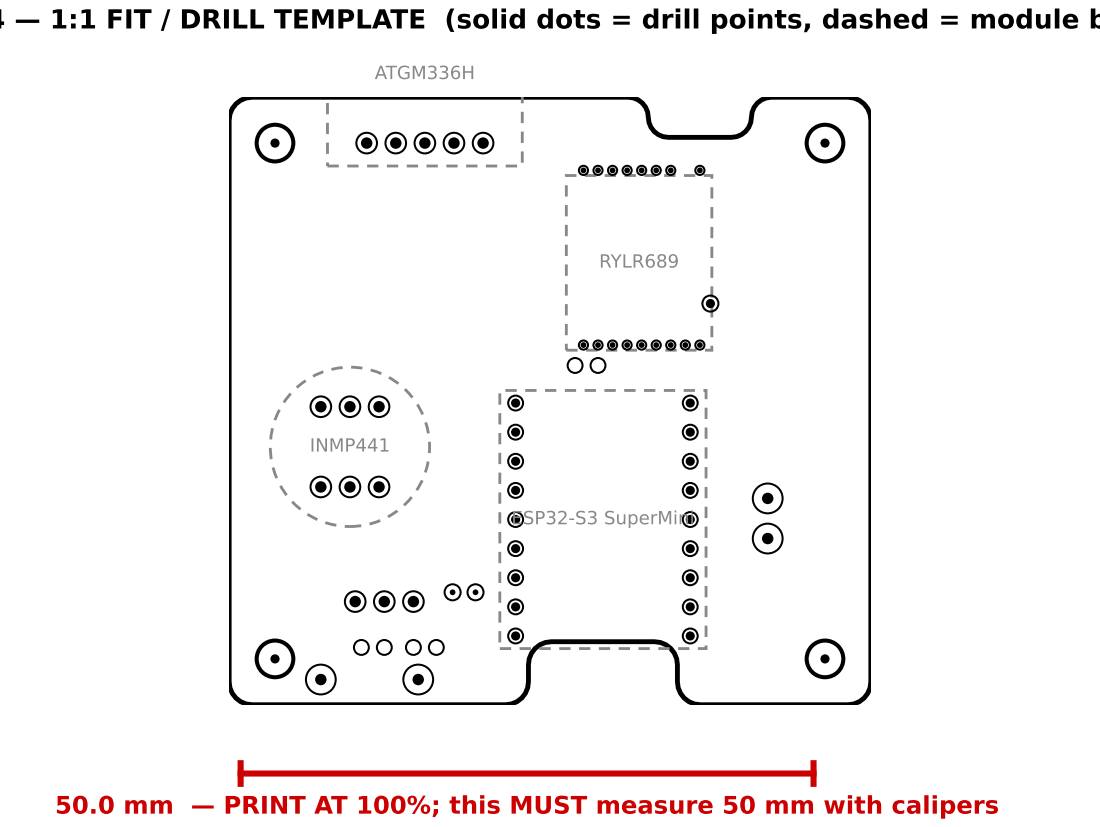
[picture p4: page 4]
ESP32-S3 SuperMini; INMP441; ATGM336H; RYLR689

PAGE 4 — 1:1 FIT / DRILL TEMPLATE (solid dots = drill points, dashed = module bodies)

50.0 mm — PRINT AT 100%; this MUST measure 50 mm with calipers

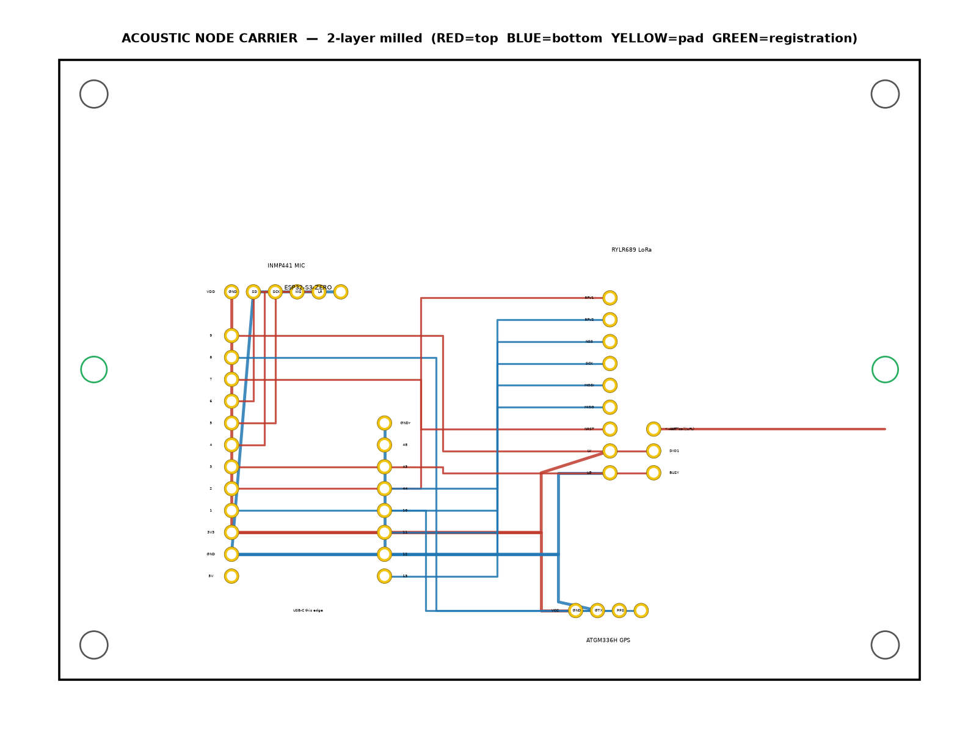
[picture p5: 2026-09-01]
pcb/node_pcb_preview.png

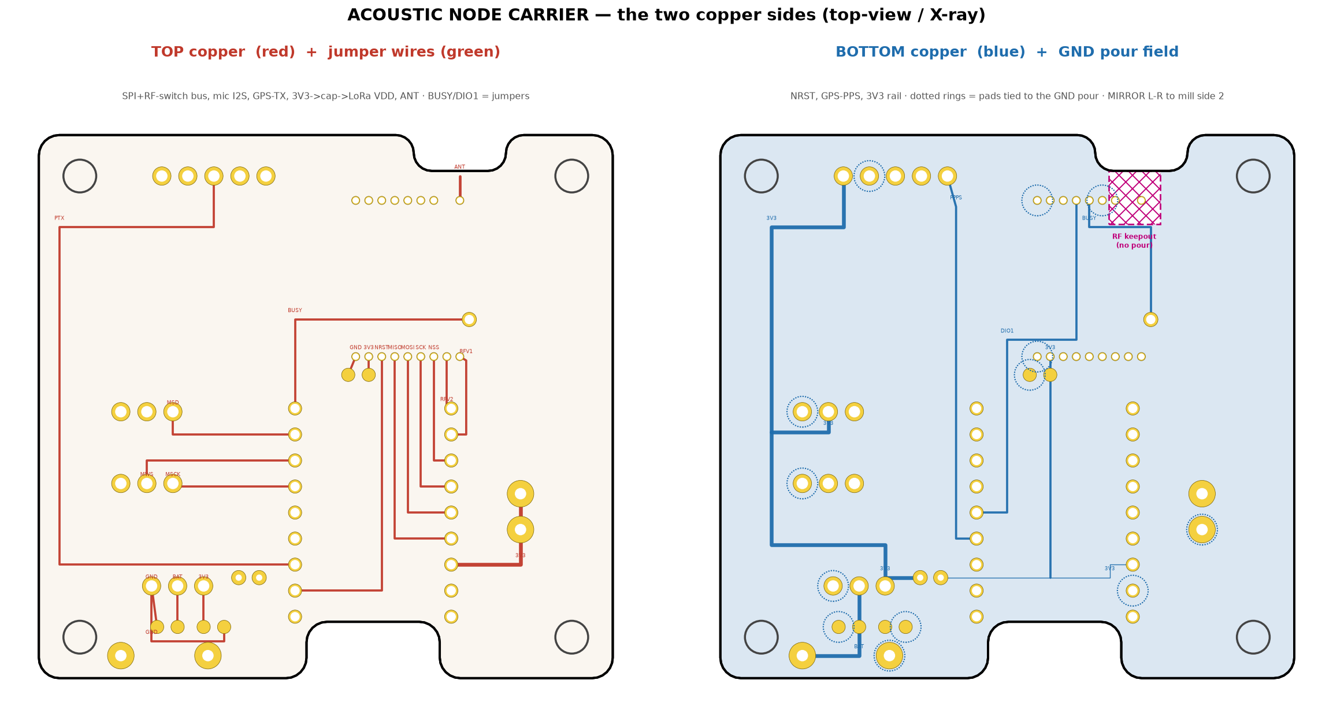
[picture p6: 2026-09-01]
pcb/out/node_sides.png

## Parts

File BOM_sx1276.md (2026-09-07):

# Acoustic Triangulation — BOM (SX1276 / XL1276-P01 variant, v3 manufactured PCB)

> ⚠️ **UNTESTED VARIANT** — PCB gerbers are generated and verified for correctness,
> but no boards have been ordered or soldered yet. Use [BOM.md](../BOM.md) (RYLR689 v2)
> if you need a working node today. This file tracks the v3 SX1276 variant for future production.

> **Radio: XL1276-P01 (Semtech SX1276, 915 MHz, SPI).** Simpler wiring than RYLR689:
> only NSS/SCK/MOSI/MISO/RST/DIO0 — no RF-switch lines, no BUSY pin. GP7 + GP8 freed.
> Firmware default in `node_config.h` — **no build flags needed**.

> **PCB: v3.0-sx1276 manufactured board** (56×53 mm, 2-layer FR4, JLCPCB).
> Replaces hand-wiring. See [`pcb/fab_guide_sx1276.md`](pcb/fab_guide_sx1276.md)
> for ordering instructions, Gerber checklist, and pricing.

Prices = AliExpress/Amazon best-deal tier, USD, Sep 2026. Buy 1–2 spares on cheap parts.

---

## On-board components (soldered to the PCB — per node)

| # | Item | Footprint | Unit $ | Qty/node | Line $ |
|---|---|---|---|---|---|
| U1 | ESP32-S3-Zero (S3FH4R2, 4 MB flash 2 MB PSRAM) | 2×9 2.54mm TH header | 4.50 | 1 | 4.50 |
| U2 | XL1276-P01 SX1276 915 MHz LoRa module | 16×16mm SMD castellation | 12.00 | 1 | 12.00 |
| U3 | INMP441 I²S MEMS mic module | 2×3 2.54mm TH header | 1.80 | 1 | 1.80 |
| U4 | ATGM336H GPS module (PPS pin required) | 1×5 2.54mm TH header | 4.50 | 1 | 4.50 |
| U5 | MCP1700-3302E/TO-92 LDO (or HT7333-A) | TO-92 TH | 0.30 | 1 | 0.30 |
| C1 | 10 µF 16V MLCC 0805 (local LoRa VCC decoupling) | 0805 SMD | 0.05 | 1 | 0.05 |
| C2 | 470 µF 10V low-ESR electrolytic, radial 8mm | TH 3.5mm pitch | 0.40 | 1 | 0.40 |
| Cin | 1 µF 25V MLCC 0805 (LDO input cap) | 0805 SMD | 0.03 | 1 | 0.03 |
| Cout | 1 µF 25V MLCC 0805 (LDO output cap) | 0805 SMD | 0.03 | 1 | 0.03 |
| L1 | 600 Ω @ 100 MHz ferrite bead 0805 (e.g. BLM21PG601SN1) | 0805 SMD | 0.05 | 1 | 0.05 |
| J1 | 2-pin screw terminal or solder pads for battery | TH 2.54mm (B+ B−) | 0.15 | 1 | 0.15 |
| — | PCB (v3.0-sx1276, JLCPCB 2-layer FR4) | — | ~1.80 | 1 | 1.80 |
| | **Per-node board subtotal** | | | | **~$25.60** |

> **XL1276-P01 pinout:** Footprint uses the ACTUAL verified pinout from the XL1276-D01
> datasheet — NOT Ra-01S-compatible. Left col: ANT GND GND DIO1 DIO2 DIO3 DIO4 DIO5.
> Right col: GND VCC DIO0 RST SCK MISO MOSI NSS (top→bot). DIO0 is on the right column.
> **Verify VCC and GND with a multimeter before first power-on.**
> If pitch differs from 2 mm, adjust `LORA_PW`/`LORA_PH` and regenerate.

---

## Field node ×4 (solar, weatherproof)

| # | Item | Unit $ | Qty | Line $ |
|---|---|---|---|---|
| — | PCB + on-board components (above) | 25.60 | 4 | 102.40 |
| P1 | 6 V 5 W solar panel (110×136 mm) | 8.00 | 4 | 32.00 |
| P2 | CN3791 1S Li-ion MPPT solar charger module | 3.00 | 4 | 12.00 |
| P3 | 18650 Li-ion cell ×1 + holder (lean) | 5.00 | 4 | 20.00 |
| P4 | 1N5822 Schottky diode (solar/USB coexist) | 0.15 | 4 | 0.60 |
| E1 | IP65 ABS enclosure ~100×68×50 mm | 4.50 | 4 | 18.00 |
| E2 | Acoustic vent / PTFE membrane | 1.50 | 4 | 6.00 |
| E3 | M3 nylon standoffs ×4 (mount PCB in box) | 0.50 | 4 | 2.00 |
| E4 | Wire, JST, heat-shrink, pole mount | 5.00 | 4 | 20.00 |
| | **Field-node subtotal (lean power)** | | | **~$213** |

Battery options: 2× 18650 (+$4/node, ~3.5-day autonomy) · 3× (+$8/node, ~5 days)
· 1× 32700 LiFePO₄ (+$5/node, safer in hot enclosures, ~4.2 days)

---

## Office node ×1 (mains, USB-powered from Pi)

| # | Item | Unit $ | Qty | Line $ |
|---|---|---|---|---|
| — | PCB + on-board components | 25.60 | 1 | 25.60 |
| H1 | Active external GPS antenna (SMA, 3V, 28 dB) | 4.50 | 1 | 4.50 |
| H2 | Small enclosure + USB-C cable | 4.50 | 1 | 4.50 |
| | **Office-node subtotal** | | | **~$35** |

---

## Base compute + bench-dev

| # | Item | Unit $ | Qty | Line $ |
|---|---|---|---|---|
| B1 | Raspberry Pi (on hand) | 0 | 1 | 0 |
| B2 | microSD 16 GB+ | 6.00 | 1 | 6.00 |
| D1 | ESP32-S3-DevKitC-1 (bench / extra node dev) | 8.00 | 1 | 8.00 |

---

## Totals

| Group | v2 (RYLR689 breadboard) | v3 (SX1276 manufactured PCB) |
|---|---|---|
| 4 field nodes | $189 | **$213** |
| 1 office node | $28 | **$35** |
| Base + bench | $14 | $14 |
| **Total** | **~$231** | **~$262** |

The ~$31 increase buys: manufactured PCBs (no hand-wiring, 5 boards), XL1276-P01
modules (2-3× pricier than RYLR689), and 4 free GPIOs per node.

---

## 15-unit batch (for sharing with a friend)

| Item | 15× qty | Estimated $ |
|---|---|---|
| XL1276-P01 modules | 15 | ~$90–120 (AliExpress ~$6–8 ea) |
| ESP32-S3-Zero | 15 | ~$45–60 |
| INMP441 mic | 15 | ~$15–25 |
| ATGM336H GPS | 15 | ~$35–50 |
| PCB (15 pcs JLCPCB) | 15 | ~$17–28 incl. shipping |
| Passives (U5, C1/C2, L1, etc.) | 15 sets | ~$20 |
| **15-board electronics subtotal** | | **~$220–280** |

Solar/enclosure/battery ordered separately per deployment. See
[`pcb/fab_guide_sx1276.md`](pcb/fab_guide_sx1276.md) for the exact JLCPCB quote
procedure and shipping options.

---

## Buy links (verify variant/price at order)

- **XL1276-P01** (SX1276, 915 MHz): [Amazon JESSINIE B0BXDNFZ2B](https://www.amazon.com/dp/B0BXDNFZ2B) ~$12 · AliExpress "XL1276-P01" ~$5–8
- **ESP32-S3-Zero**: [AliExpress "ESP32-S3-Zero"](https://www.aliexpress.com/item/1005007088521314.html) ~$4.50
- **INMP441**: [AliExpress ~$1.61](https://www.aliexpress.com/item/32962426410.html)
- **ATGM336H** (with PPS pin): [AliExpress ~$2.66](https://www.aliexpress.com/item/33034354199.html)
- **MCP1700-3302E**: Mouser / DigiKey ~$0.30
- **470 µF low-ESR 10V radial**: DigiKey / LCSC
- **6 V 5 W solar**: [Waveshare](https://www.waveshare.com/solar-panel-6v-5w.htm)
- **CN3791 MPPT**: [ICStation](https://www.icstation.com/cn3791-charging-mppt-solar-power-panels-lithium-battery-charging-module-p-15791.html)

*Prices verified Sep 2026; treat as ±30%.*

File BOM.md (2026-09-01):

# Acoustic Triangulation — Price-Shopped BOM

> **RADIO: RYLR689 (Semtech LLCC68, 868/915 MHz).** Replaces the earlier Ra-01/
> SX1278 (433). It's a bare **SPI** LLCC68 (not an AT-command UART module), so it
> drops into the RadioLib firmware — but it needs **3 extra GPIO** vs the SX1278
> (BUSY + two RF-switch lines) and a **crystal, not a TCXO** (firmware TCXO=0.0).
> See node_config.h + WIRING.md. US ISM = **915 MHz**.

> **CURRENT PHASE: 2-node bench test.** Building **2** nodes (ESP32-S3 + INMP441 +
> ATGM336H + RYLR689) to validate the LoRa link and the make-or-break 2-node GPS
> time-sync (M2). If M2 holds, scale to the 5-node topology below **and spin a PCB**
> (which also ends the breadboard pin crunch the RYLR689 causes).

**Topology (target, after the test passes): 4 solar nodes (one per corner) + 1
office node (sensor + LoRa gateway + base, mains-powered) = 5 detection points.**
Prices = best-deal / AliExpress tier, USD, Aug 2026. Amazon/DigiKey ~1.5–2×.
Buy 1–2 spares of the cheap bits.

Battery = **Li-ion, 1S/parallel** (site doesn't freeze). **Never a LiPo pouch in
a hot box, never a USB power bank** (auto-off at ~58 mA). LiFePO4 = +~$5/node
upgrade for heat longevity.

Power note: the **5 W panel is right-sized** for continuous-GPS (~4.6 Wh/day) —
don't shrink it. Save instead on the **battery** (system tolerates a node
browning out and rejoining). Default below uses a **lean 1× 18650 (~1.5-day
autonomy)**; bump to 2–3 cells for more margin.

---

## Field node ×4 (solar, weatherproof, at corners)

| # | Item | Unit $ | Qty | Line $ |
|---|---|---|---|---|
| 1 | ESP32-S3-Zero (S3FH4R2, 2 MB PSRAM) | 4.50 | 4 | 18.00 |
| 2 | INMP441 I²S mic | 1.80 | 4 | 7.20 |
| 3 | **RYLR689** LLCC68 915 MHz **w/ spring antenna** | 9.00 | 4 | 36.00 |
| 4 | ATGM336H GPS (PPS + patch antenna) | 4.50 | 4 | 18.00 |
| 5 | 6 V 5 W solar panel | 8.00 | 4 | 32.00 |
| 6 | CN3791 1S Li-ion MPPT solar charger | 3.00 | 4 | 12.00 |
| 7 | 18650 cell ×1 (lean) + holder | 5.00 | 4 | 20.00 |
| 8 | Schottky diode + 220–470 µF cap (LDO-direct, no buck-boost) | 0.50 | 4 | 2.00 |
| 9 | IP65 ABS enclosure ~100×68×50 mm | 4.50 | 4 | 18.00 |
| 10 | Waterproof acoustic vent / PTFE membrane | 1.50 | 4 | 6.00 |
| 11 | Wire, JST, heat-shrink, pole mount | 5.00 | 4 | 20.00 |
| | **Field-node subtotal (lean power)** | | | **$189** |

Power chain: `6V solar → CN3791 → 18650 (1S) → Schottky → ESP32 5V pad → onboard LDO → 3V3` (no separate buck-boost; board takes 3.3–6 V in, USB-C coexists via the diode).
- **More autonomy:** 2× 18650 (+$4/node, ~3.5 days) or 3× (+$8/node, ~5 days).
- **Salvaged 18650s** (laptop/tool packs) → cells nearly free.
- **Mains-tap a corner** near existing power: a ~$5 weatherproof 5 V supply
  replaces items #5–8 (~−$18/node).
- **Cut draw (DS3231 holdover, design-doc Appendix A):** halves draw → a 2–3 W
  panel + 1 cell suffices; +$2 + firmware.

---

## Office node ×1 (mains: sensor + LoRa gateway + base)

Same sensor as a field node, minus solar/battery/weatherproofing, **USB-powered
from the Pi**. Receives the 4 field nodes over LoRa AND is a 5th detection point.

| # | Item | Unit $ | Qty | Line $ |
|---|---|---|---|---|
| H1 | ESP32-S3-Zero | 4.50 | 1 | 4.50 |
| H2 | INMP441 I²S mic | 1.80 | 1 | 1.80 |
| H3 | **RYLR689** LLCC68 915 MHz w/ spring antenna | 9.00 | 1 | 9.00 |
| H4 | ATGM336H GPS + **active external GPS antenna** | 8.50 | 1 | 8.50 |
| H5 | Small case + USB-C cable (Pi powers it) | 4.50 | 1 | 4.50 |
| | **Office-node subtotal** | | | **~$28** |

> **Office node needs GPS sky-view for PPS** — indoors gets no fix. Route the
> active GPS antenna to a window/roof, or mount the node on an exterior wall.

---

## Base compute + bench-dev

| # | Item | Unit $ | Qty | Line $ |
|---|---|---|---|---|
| B1 | Raspberry Pi (on hand) — solver + Leaflet map | 0 | 1 | 0 |
| B2 | microSD 16 GB+ | 6 | 1 | 6 |
| D1 | ESP32-S3-DevKitC-1 (headered, prototyping) | 8 | 1 | 8 |

> No separate LoRa dongle — the **office node IS the gateway** (its Ra-01 hears
> the field nodes; forwards them + its own detections to the Pi over USB).

---

## Totals

| Group | Cost |
|---|---|
| 4 field nodes (lean power) | $189 |
| 1 office node | $28 |
| Base (Pi on hand) + microSD | $6 |
| Bench-dev kit | $8 |
| **Project total** | **~$231** (+ Pi if not on hand) |

**2-node test build (current):** 2× [ESP32-S3-Zero $4.50 + INMP441 $1.80 +
ATGM336H $4.50 + RYLR689 $9.00] ≈ **$40** (parts on hand). No power/enclosure yet.

Add-ons: +$4–8/node for bigger battery; −$18/node per corner you can mains-tap;
+$20 total for LiFePO4 field cells.

---

## Data flow
```
[Corner node 1..4]  --LoRa 915-->  [Office node ESP32]  --USB-->  [Pi]
     (solar sensor)                 (gateway + 5th sensor)      (solver + Leaflet map)
```

## Ordering gotchas
- **RYLR689 with bundled coil antenna** — **solder the coil to the ANT pad
  (pin 10) before ANY TX**; keying the +22 dBm PA into an open can damage it.
- **RYLR689 is a bare SPI LLCC68** (good — uses RadioLib), NOT the AT-command
  UART type. Needs BUSY + RFSW_V1/RFSW_V2 wired, and TCXO=0.0 (it has a crystal).
- **ATGM336H must have the PPS pin** broken out — confirm on the listing.
- **Office node = active external GPS antenna**; field nodes = patch antenna at
  top of enclosure (sky view).
- **Acoustic vent** (#10) so the sealed box doesn't muffle the mic.
- **Li-ion:** genuine cells, wire **1S/parallel**, add a 1S protection board or
  use protected cells. Bare pack — **not** a USB power bank.

## Buy links (verify variant/price at order)
- [ESP32-S3-Zero](https://www.amazon.com/Development-Bluetooth-ESP32-S3FH4R2-XYGStudy-ESP32-S3-Zero/dp/B0CN8KMKHJ) (cheaper on AliExpress) ·
  [INMP441 ~$1.61](https://www.aliexpress.com/item/32962426410.html) ·
  [ATGM336H ~$2.66](https://www.aliexpress.com/item/33034354199.html)
- [RYLR689 (LLCC68 915 MHz, SPI)](https://www.amazon.com/RYLR689-Wireless-Include-Antenna-Interface/dp/B0BNVKQ9JD) ·
  [6 V 5 W panel](https://www.waveshare.com/solar-panel-6v-5w.htm) ·
  [CN3791 charger](https://www.icstation.com/cn3791-charging-mppt-solar-power-panels-lithium-battery-charging-module-p-15791.html) ·
  [IP65 box](https://www.aliexpress.us/item/3256811371680313.html)

*Prices verified Aug 2026 (AliExpress/Waveshare/Amazon); treat as ±30%.*

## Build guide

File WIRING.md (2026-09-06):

# Node Wiring

## Power (field node: solar + 18650 + CN3791, LDO-direct — no buck-boost)

Use the ESP32-S3's own input pad (accepts 3.3–6 V) + onboard LDO. No separate
regulator.

```
 6V panel ─► CN3791(IN) ──MPPT──► CN3791(BAT) ═╦═ 18650 (+protection)
                                               ║
                                        [Schottky diode]
                                               ║
                                     ESP32-S3 "5V" pad ─► onboard LDO ─► 3V3 out
                                               │                          │
                                               └── USB-C (coexists) ──┐    ├─► RYLR689 (+bulk cap)
                                                                      │    ├─► INMP441
                                                                      │    └─► ATGM336H
```

The CN3791 **BAT** terminals ARE the battery rail — cell + load both tap there.

| From | To |
|---|---|
| Solar + | CN3791 IN+ |
| Solar − | CN3791 IN− |
| CN3791 BAT+ | 18650 + (via protection) |
| CN3791 BAT− | 18650 − |
| CN3791 BAT+ → **Schottky diode** → | ESP32 **5V** pad |
| CN3791 BAT− | ESP32 **GND** |
| ESP32 **3V3 out** | RYLR689 3.3V, INMP441 VDD, ATGM336H VCC |
| GND rail | RYLR689 GND, INMP441 GND **+ L/R**, ATGM336H GND |
| **220–470 µF cap** | across 3V3–GND near the RYLR689 (TX spike) |

**Gotchas**
1. **Series Schottky** (BAT+ → 5V pad) lets USB-C + battery coexist — flash over
   USB anytime, no back-feed into the cell.
2. **Bulk cap on 3V3 near RYLR689** for the ~120 mA LoRa-TX transient.
3. Match CN3791 MPPT set-point to the 6 V panel (MPP ~5 V); many ship for 9/12 V.
4. INMP441 `L/R` → GND (left channel; silent if floating).
5. Protected cell or a 1S protection board between cell and BAT; set low-voltage
   cutoff ~3.2–3.3 V (LDO sags below that — fine, ~90 % of cell used).
6. *(Optional)* add a buck-boost back only if you want a rock-stable 3.3 V to the
   very bottom of the cell.

Office node: no solar/charger/battery — powered from the Pi's USB-C (5 V → onboard
LDO → 3V3). Everything else identical.

## Signals — RYLR689 (LLCC68) node  [see also node_config.h]

Radio changed from Ra-01 / SX1278 → **RYLR689 / LLCC68**. It's a bare SPI module
(not AT-command UART), so RadioLib drives it, but it needs 3 pins the SX1278
didn't: **BUSY** + the two antenna **RF-switch** lines (RFSW_V1/V2). It also runs
on a **32 MHz crystal, not a TCXO** → firmware passes `TCXO = 0.0` (a nonzero
value makes `begin()` fail — this was the #1 first-try trap).

```
INMP441 I²S:  BCLK=GP4   WS=GP5   SD=GP6                 (L/R -> GND, left ch)
RYLR689 SPI:  SCK=GP12   MISO=GP13  MOSI=GP11  NSS=GP10
              RST=GP7    DIO1=GP9   BUSY=GP3
              RFSW_V1=GP2   RFSW_V2=GP8*             (*link test; see crunch)
ATGM336H:     GPS_TX->GP1 (ESP RX)   PPS=GP8              (ESP->GPS TX unused)
```

RYLR689 module pins → ESP: `1,13,18=GND  2=VDD(3V3)  3=NRESET→GP7  4=MISO→GP13
5=MOSI→GP11  6=SCK→GP12  7=NSS→GP10  9=RFSW_V1→GP2  8=RFSW_V2  14=BUSY→GP3
15=DIO1→GP9  10=ANT→coil`. Leave DIO2/DIO3 (16/17) unconnected.

### Two-phase bring-up (breadboard)
**Phase 1 — radio-only link test** (`lora_tx_llcc` / `lora_rx_llcc`): mic + GPS
NOT connected, so the whole GP1–13 header is free. Wire the RYLR689 as above with
**RFSW_V2 → GP8**. Both boards identical. Expect RX lines with RSSI ≈ −30…−60 dBm
a few metres apart.

**Phase 2 — full node / 2-node sync** (`twonode_llcc`): add mic + GPS. Now
mic(3) + GPS(2) + RYLR689(9) = 14 signals vs 13 header pins. Reconcile:
- **Move the INMP441 `L/R` wire from GP3 to the GND rail** (it just needs to be
  low). That frees GP3 for **BUSY**.
- **GP8 is now PPS**, so RFSW_V2 moves to **GP44 (the "RX" header pin)**. The
  USB-CDC console frees UART0, so RX=GP44 / TX=GP43 are usable GPIO — 13 + 2 = 15
  pins for 14 signals. Build with `-D PIN_LORA_RFSW2=44`; GP43 (TX) stays spare.
  No solder pad, no extra part, real BUSY — the same two-GPIO RF-switch topology
  the **PCB** uses, so the breadboard is electrically identical to the final board.

---

## Signals — XL1276-P01 (SX1276) node  [manufactured PCB v3 / node_config.h default]

**3 fewer control pins** vs RYLR689: no BUSY, no RFSW_V1/V2. The SX1276 integrates
the antenna switch. GP7 and GP8 are now free (DS3231 RTC, status LED, etc.).

```
INMP441 I²S:     BCLK=GP4   WS=GP5   SD=GP6            (L/R → GND, left ch)
XL1276-P01 SPI:  SCK=GP11   MISO=GP13  MOSI=GP12  NSS=GP10
                 RST=GP44   DIO0=GP9
ATGM336H:        GPS_TX→GP1 (ESP RX)   PPS=GP2
```

XL1276-P01 module pins → ESP (actual XL1276-P01 pinout, verified from datasheet):

| Module pin | Signal | ESP GPIO |
|---|---|---|
| Right col, pin 10 (2nd from top) | VCC (3.3 V) | 3V3 rail |
| Right col, pin 11 (3rd from top) | DIO0 / IRQ | GP9 |
| Right col, pin 12 (4th from top) | RST | GP44 (RX pin) |
| Right col, pin 13 (5th from top) | SCK | GP11 |
| Right col, pin 14 (6th from top) | MISO | GP13 |
| Right col, pin 15 (7th from top) | MOSI | GP12 |
| Right col, pin 16 (8th/bot) | NSS / CS | GP10 |
| Right col, pin 9 (top) | GND | GND rail |
| Left col, pin 1 (top) | ANT | wire antenna |
| Left col, pins 2-3 | GND | GND rail |
| Left col, pins 4-8 | DIO1-DIO5 | NC |

> **Critical:** DIO0 is on the RIGHT column (pin 11), not the left. This module
> is NOT Ra-01S-compatible — the pinout is different. Verify VCC and GND with
> a multimeter before applying power. **Never assume Ra-01S pinout.**

### Breadboard bring-up (XL1276-P01)

**Phase 1 — radio link test** (`lora_tx` / `lora_rx`): wire only NSS, SCK,
MOSI, MISO, RST, DIO0, VCC, GND. No mic, no GPS. Expect RSSI ≈ −30…−60 dBm
at close range.

**Phase 2 — full node** (`stage4`): add mic + GPS. Pin budget:

| Group | Signals | GPIOs used |
|---|---|---|
| I²S mic | BCLK, WS, SD | GP4, GP5, GP6 |
| SPI radio | NSS, SCK, MOSI, MISO | GP10, GP11, GP12, GP13 |
| Radio control | RST, DIO0 | GP44, GP9 |
| GPS | GPS_TX, PPS | GP1, GP2 |
| **Total** | **10 signals** | **GP43 + GP3 + GP7 + GP8 spare** |

With the XL1276-P01 you have **4 spare GPIOs** on the S3-Zero vs 0 with the
RYLR689. The defaults in `node_config.h` already target this pinout — no build
flags needed.

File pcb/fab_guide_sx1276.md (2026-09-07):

# JLCPCB Fabrication Guide — Acoustic Node Carrier v3.0-sx1276

> ⚠️ **UNTESTED** — Gerbers are ready and pinout-verified, but no boards have been
> manufactured or assembled yet. Review all pads against your physical XL1276-P01
> module with calipers and a multimeter before submitting to fab.

Board: **56 × 53 mm**, 2-layer FR4, XL1276-P01 / SX1276 variant.

---

## Step 1 — Finish the PCB in KiCad (required before ordering)

The script `gen_pcb_sx1276.py` produces the copper traces and pad footprints but
**does not generate the GND fill** (requires a polygon-pour tool). Do this once:

1. **Import gerbers into KiCad**
   `File → Import → Gerber` → select all files in `out_sx1276/`

2. **Add B_Cu GND fill zone**
   - Switch to B_Cu layer
   - `Place → Add Rule Area` → check "Copper fill", net = GND
   - Draw zone outline around the full board
   - `Edit → Fill All Zones` (shortcut `B`)

3. **RF keepout near ANT pad**
   - The XL1276-P01 ANT pad (left col, top) is at upper-left of the module
   - Add a B_Cu keepout rectangle (~10 × 10 mm) around the ANT pad and the
     area above the module where the wire antenna will sit
   - This prevents the GND pour from adding shunt capacitance to the antenna feed

4. **Run DRC**
   `Inspect → Design Rules Checker → Run DRC`
   Fix any clearance violations. Common issues:
   - 3V3 crossing trace (CROSSW = 0.2 mm) may be tight — JLCPCB min is 0.1 mm, fine
   - Verify XL1276-P01 pads are not flagged as overlapping module body

5. **Re-export gerbers**
   `File → Plot → Gerber` — use default KiCad layer mapping
   `File → Fabrication Outputs → Drill Files`
   Zip the exported files.

---

## Step 2 — JLCPCB Quote (15 units)

Go to **[jlcpcb.com](https://jlcpcb.com)** → "Order Now" → upload the zip.

### Recommended settings for 15 pcs

| Option | Value |
|---|---|
| Layers | **2** |
| Dimensions | Auto-detected (56 × 53 mm) |
| PCB Qty | **15** (JLCPCB supports any qty ≥ 5) |
| PCB Thickness | **1.6 mm** |
| PCB Color | **Green** (cheapest; any color same price at this qty) |
| Silkscreen | White (default) |
| Surface Finish | **HASL (with lead)** — cheapest, fine for TH solder joints |
|  | ENIG (+$15 for the order) if you want cleaner SMD pad finish |
| Copper Weight | **1 oz** |
| Min Hole Size | 0.8 mm (ESP/mic/GPS headers) — well within JLCPCB 0.2 mm min |
| Min Track/Spacing | 0.4 / 0.2 mm — standard tier |

> **HASL vs ENIG:** HASL is fine for all TH pads and the SMD castellation pads.
> ENIG gives a flatter surface that's easier to inspect after soldering the XL1276-P01.
> Pick ENIG if you're sharing boards with a friend who's less experienced soldering.

### Estimated pricing (Sep 2026)

| Item | Cost |
|---|---|
| 15 × PCB (56×53 mm, 2-layer, HASL, green) | **$13–18** |
| DHL Express shipping to US (~5–7 days) | **$22–28** |
| **Total for 15 boards** | **~$35–46** |
| Per-board cost | **~$2.30–3.10** |

> JLCPCB sometimes runs promotions: new-account first order ~$2 for 5 pcs.
> For 15 units there's no promo, but the price is stable. Verify at checkout —
> the calculator on the site is real-time.

> **Economy shipping** (JLCPCB Global Standard, ~15–25 days): ~$7–12 shipping,
> total ~$20–30 for 15 boards. Fine if you're not in a rush.

---

## Step 3 — Pre-order checklist

- [ ] GND pour added and filled in KiCad
- [ ] RF keepout set around ANT pad
- [ ] DRC passes with 0 errors
- [ ] Preview gerbers in [JLCPCB Gerber Viewer](https://gerber-viewer.jlcpcb.com/) — verify pad positions
- [ ] XL1276-P01 modules in hand — **measure the castellation pitch** with calipers
      before committing. Confirm 2 mm pitch and 16 × 16 mm body.
      If pitch differs, adjust `LORA_PW`/`LORA_PH` in `gen_pcb_sx1276.py` and regenerate.
- [ ] Confirm the exact pinout of your batch (VCC / GND / DIO0 position) with a multimeter

---

## Step 4 — Soldering order (recommended)

1. **SMD passives first** (C1, Cin, Cout, L1) — hardest to reach after modules
2. **U5 LDO** (MCP1700 TO-92) + battery terminals
3. **XL1276-P01** — solder castellation pads, inspect under magnification
4. **ESP32-S3-Zero** — insert into header pins, solder from below
5. **INMP441 + ATGM336H** — header pins, straightforward
6. **C2 electrolytic** — polarity: + to 3V3, − to GND (labelled on silkscreen)

**First power-on:** before inserting the ESP, apply 3.3 V to the board rails
and verify current draw < 15 mA (GPS + LoRa idle, no ESP). Then insert ESP and
proceed with `pio run -e lora_tx -t upload -t monitor`.

---

## Layer-to-filename reference (for JLCPCB upload)

| File | Content | JLCPCB auto-detected? |
|---|---|---|
| `node_sx1276-F_Cu.gtl` | Front copper | ✅ |
| `node_sx1276-B_Cu.gbl` | Back copper (+ GND pour from KiCad) | ✅ |
| `node_sx1276-F_Mask.gts` | Front soldermask openings | ✅ |
| `node_sx1276-B_Mask.gbs` | Back soldermask openings | ✅ |
| `node_sx1276-F_Silk.gto` | Front silkscreen | ✅ |
| `node_sx1276-Edge_Cuts.gko` | Board outline | ✅ |
| `node_sx1276.drl` | Drill file (Excellon, metric) | ✅ |

JLCPCB's auto-detection recognizes standard KiCad extensions. If it asks you to
manually assign layers, match the table above.

---

## Design notes

### Why no B_Cu silkscreen?
Component labels are on F_Cu silkscreen only — the bottom is the GND pour,
no room for text.

### C2 position
The 470 µF bulk capacitor is at upper-right (x≈50 mm) to clear the RST routing
lane. Use a standard **8 mm body, 3.5 mm lead pitch** radial cap. The PCB pad
spacing matches 3.5 mm exactly.

### XL1276-P01 antenna clearance
The wire antenna solders to the ANT castellation pad at the top of the left column.
The antenna wire can exit through a small hole in the enclosure lid or through the
acoustic vent grommet. The PCB has ~8 mm of board real-estate above the module
before the GPS header — route the antenna up and over the board edge.

### Power chain reminder
```
Solar (6V) → CN3791 MPPT → 18650 (1S) → Schottky 1N5822 → ESP32 5V pad
                                                                    │
                                                          MCP1700 LDO → 3.3V rail
                                                                    │
                                                     XL1276-P01 · INMP441 · GPS
```
The Schottky diode is **off-board** (between the CN3791 BAT+ and the ESP 5V pad
solder wire). It is NOT on the PCB — solder it inline on the power wire.

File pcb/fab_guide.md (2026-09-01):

# Acoustic Node Carrier — CNC Milling Guide

2-layer through-hole carrier for one node: **ESP32-S3-Zero + INMP441 mic +
ATGM336H GPS + RYLR689 LoRa**. Designed for **isolation milling on a hobby CNC**
with **unplated** holes and a **flip for the second side**.

Board: **84 × 58 mm**, matches the firmware net map (`node_config.h`).

## Files (`out/`)
| File | Layer |
|---|---|
| `node-F_Cu.gtl` | TOP copper (red in preview) |
| `node-B_Cu.gbl` | BOTTOM copper (blue) |
| `node-Edge_Cuts.gko` | board outline |
| `node.drl` | Excellon drill (all holes) |
| `node_preview.png` | labeled preview |

## ⚠ Verify before you cut copper
This is a **complete, correct netlist** and a milling-optimized layout, but it is
a **starting design generated programmatically** — treat it like a first draft:
1. **Footprints are 2.54 mm headers.** Confirm the **ESP32-S3-Zero** pad order/pitch
   and the **RYLR689** castellated pad layout against *your* actual parts and adjust
   pad positions if they differ. (The RYLR689 is a 16×16 mm castellated SMD module —
   you'll either solder it edge-on to pads or use a breakout.)
2. **Open the Gerbers in FlatCAM (or import to KiCad) and eyeball for same-layer
   crossings** before generating toolpaths. On a milled board two traces touching
   on one layer = a short. The router splits top/bottom, but verify — nudge any
   crossing to the other layer or reroute.
3. Run your CAM tool's isolation preview at your actual tool width.

## Milling parameters  (v2.1 — matches the current Gerbers/`node.drl`)
- **Isolation tool:** **fine V-bit, ~0.1 mm tip, 20–30°.** The board is a **uniform
  0.47 mm** isolation floor *everywhere* (set by the LoRa 1.27 mm pitch — no tighter
  spots). That is millable at **constant Z** on a small flattened blank — **no height
  map required.** Still: sharp V-bit, low spindle runout, and surface the spoilboard
  flat + stick the blank down fully so it's true to the machine.
- **Traces:** 0.8 mm signal · 1.4 mm power · **0.3 mm** at the single column crossing.
- **Drills (from `node.drl`, 4 tools):**
  - **0.5 mm** — LoRa module pads + JP1 ferrite via-in-pad
  - **0.8 mm** — ESP pads + BUSY via
  - **1.0 mm** — mic / GPS / LDO / battery / C2 leads
  - **3.2 mm** — M3 corner holes (×4; these also do the flip-registration)
- **Outline / notches / RF keepout:** **1.0–1.5 mm 2-flute flat end mill** — board edge,
  USB-C + ANT notches, and pocketing the RF-keepout rectangle. Leave tabs to hold it.

## Double-sided workflow (the flip) — M3 corner holes = registration
The **four M3 corner holes** double as registration (no separate dowels):
1. Drill all holes (incl. the four 3.2 mm corners) through the stock first.
2. Put two **M3 screws/dowel pins** through diagonal corners into your spoilboard.
3. Mill **bottom** copper (`B_Cu`). Lift, **flip about the vertical axis**, drop back
   onto the same two corner pins → orientation preserved. Mill **top** (`F_Cu`).
   - In CAM, mirror the top layer about the **Y axis** (vertical) so it matches the flip.
4. Cut the outline + notches last.

## Unplated holes — handling the few cross-layer nets
Holes are **not plated**, so a pin only connects to copper on the side you solder.
This layout is arranged so **most nets need only the bottom side**, and where a net
uses top copper it lands on a **component pad you can solder on top too**. Practical
rules at assembly:
- **Header/module pins that carry a top-layer trace:** solder them on **both** sides
  (or bend a tiny wire). The preview shows which pads have red (top) traces.
- **3V3 and GND:** soldered both sides at the module pads (they're the wide traces).
- There are **no blind vias** — every cross-layer point is at a solderable pad.

## Assembly order
0. **RF keepout (v2):** when generating the bottom isolation/pour, exclude the magenta
   keepout box at the antenna feed (`ANT`/`ANT_PAD` are the module's 50 Ω RF output) —
   leave that rectangle bare copper-free so the ground pour doesn't detune the antenna.
1. Mill both sides + drill + outline; deburr holes.
2. Solder the **RYLR689** first (tightest). Coil/uFL antenna to the **ANT** pad
   (never power it without an antenna).
3. Solder **ESP32-S3-Zero** (2 header rows), then **mic** and **GPS** headers.
4. Solder both-sides where the preview shows a top trace on a pin.
5. Confirm **L/R → GND** on the mic (left channel); **ANT**/**ANT_PAD** and their feed
   are clear of ground (the v2 keepout) — **ANT_PAD (pin 12) stays unconnected**.
6. Flash `twonode_llcc` (node 1) / `twonode_b_llcc` (node 2), verify per FIELD_TEST.md.

## Net map (what connects to what)
ESP32-S3-Zero →
```
GP1  ← GPS TX (NMEA)      GP7  → LoRa NRST        GP12 → LoRa SCK
GP2  → LoRa RFSW_V1       GP8  ← GPS PPS          GP13 → LoRa MISO
GP3  → LoRa BUSY          GP9  → LoRa DIO1        GP44 → LoRa RFSW_V2
GP4  → Mic SCK(BCLK)      GP10 → LoRa NSS         3V3  → mic/gps/lora VDD
GP5  → Mic WS            GP11 → LoRa MOSI         GND  → mic/gps/lora GND + mic L/R
GP6  → Mic SD             GP43 = spare (TX)       GP48 = onboard RGB (no wire)
```
GPS RX pin = **no-connect** (we only read the GPS). LoRa module GND on 3 pads → tie all to GND.

## BOM (per node)
| Ref | Part | Notes |
|---|---|---|
| U1 | ESP32-S3-Zero (S3FH4R2) | the MCU |
| U2 | INMP441 I²S mic | L/R→GND |
| U3 | ATGM336H GPS (w/ PPS) | active antenna for enclosed sites |
| U4 | RYLR689 (LLCC68, 915 MHz) | +915 coil/uFL antenna |
| — | 2.54 mm headers | per module |
| — | 2× 3.0 mm dowel pins | registration (reusable) |
| — | 4× M3 hardware | mounting |
| PCB | single-sided-clad? **use 2-layer clad** FR1/FR4 | FR1 mills cleaner than FR4 |

**Tip:** FR1 (paper-phenolic) or CEM machines much nicer than FR4 for isolation
milling (less fiberglass dust, cleaner edges). For 2 boards, panelize both on one
sheet with shared registration dowels.

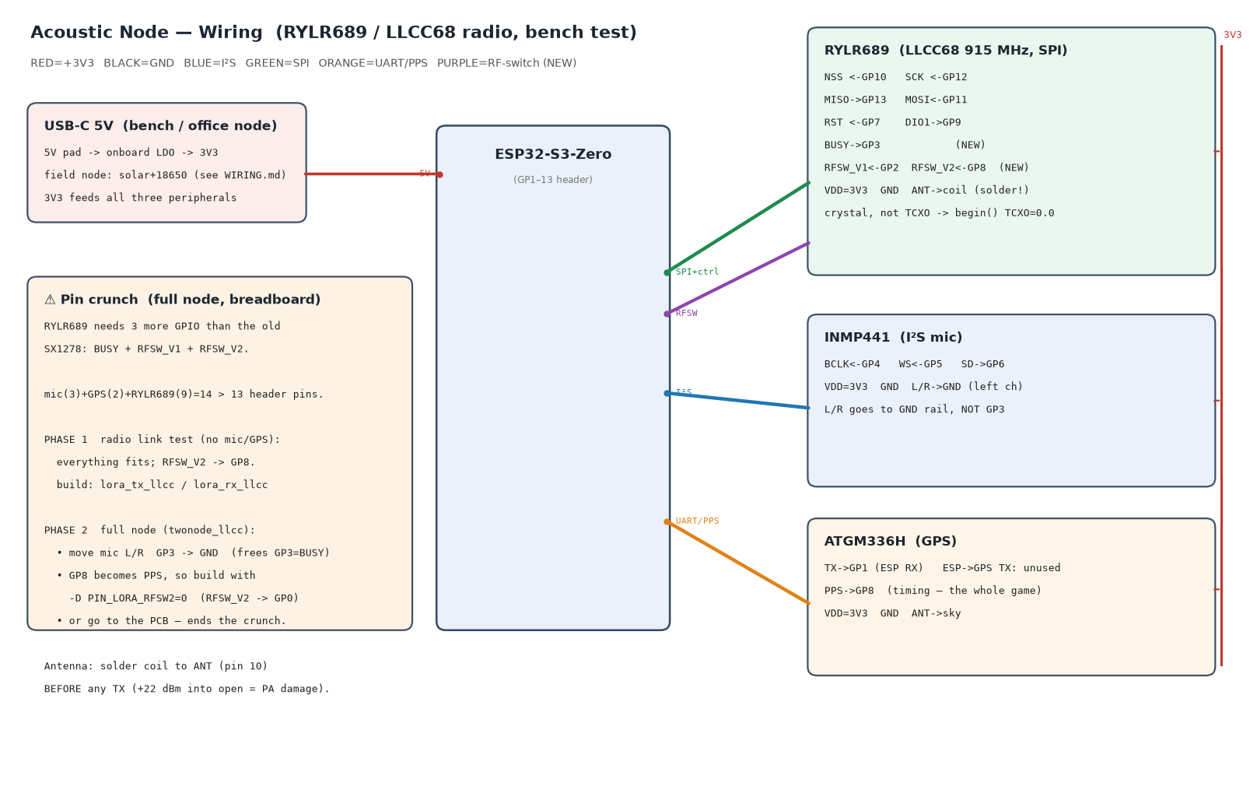
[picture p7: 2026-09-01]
wiring_diagram.png

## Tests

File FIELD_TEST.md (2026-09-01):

# PPS Δt Field Test — the make-or-break

Goal: prove two nodes agree on time to sub-millisecond via GPS-PPS, by clapping
between them and checking the measured Δdistance matches the real geometry.

## What you need
- Both nodes on USB battery packs.
- A spot **outdoors with open sky** (a window is not enough — the GPS needs sky).
- A tape measure (or a known distance/landmarks).
- A sharp loud sound: a hard hand-clap is fine at bench-to-~40 ft; two boards
  smacked together carries farther.
- Laptop only if you want the numbers (LEDs alone give go/no-go). If you bring it,
  read **one** node's serial — each node reports the full Δt.

## LED = the whole state (no laptop needed to run it)
| LED | meaning |
|---|---|
| **RED blink** | no GPS fix yet (waiting for satellites) |
| **YELLOW blink** | has satellites, still locking (averaging position + PPS) |
| **GREEN solid** | **locked + clock ready — GO** |
| BLUE flash | this node heard a sound |
| CYAN flash | heard the other node's report over LoRa |
| **MAGENTA flash** | **PAIR — Δt computed between the two nodes** |

## Procedure

### 1. Place first, then power (important)
Each node **averages its position over the first ~60 GPS fixes** and freezes it.
So put both nodes at their **final spots first**, then power them and let them
lock. If you move a node after it locks, its reported position is stale.
- Set them a **measured distance apart** — e.g. **10 m (33 ft)**. Write it down.
- Keep them stationary and clear of your body/metal (sky view).

### 2. Wait for GREEN on both
Cold start: **~1–5 minutes** (needs a fix, then 60 fixes ≈ 60 s to lock, plus
PPS). Watch: red-blink → yellow-blink → **solid green**. Both must be green.

### 3. Test A — clock sanity (do this first)
Clap **at the exact midpoint** between the two nodes (equal distance to each).
- Expect **dt ≈ 0**, **Δdist ≈ 0** (within a few tenths of a meter).
- A large constant offset here = a clock-sync problem, not geometry.

### 4. Test B — geometry
Clap **right next to node A** (say 1 m from A).
- Expect **Δdist ≈ −(A-to-B distance)** — A hears it almost immediately, B hears
  it ~(A-B distance) later. With 10 m spacing: Δdist ≈ −9 m (from A's line).
- Then clap next to **node B** → same magnitude, **opposite sign**.

### 5. Repeat & judge
Clap each position **5+ times**. What you're looking for:
- **Test A** dt stays small and near zero (≈ within ±300 µs → <0.1 m).
- **Test B** Δdist tracks the real geometry within ~**0.5–2 m**.
- **Repeatable** across claps (consistency = timing precision).

If A is near-zero and B tracks geometry repeatably → **the GPS-PPS sync works,
sub-meter, and you're clear to build the PCB.**

## Reading the numbers (laptop)
Plug a node in and:
```
pio run -e twonode_llcc   -t monitor      # node A already flashed; just monitor
# (or -e twonode_b_llcc for node B)
```
Watch for lines like:
```
onset node=1 peak=... onset_us=...
rx node=2 onset_us=... rssi=...
>>> PAIR me(1)-node2  dt=-26100 us  Δdist=-8.95 m  (want ≈ my_dist − their_dist)
```
- `dt` = microseconds. `Δdist = dt × 343 m/s` (already computed in the line).
- Each node prints its own PAIR line (opposite signs) — reading one is enough.
- MAGENTA flash on the LED == a PAIR line just printed.

## Reading it on the uConsole (Kali/Linux) instead of the Mac
Connect the uConsole to **node A (NODE_ID 1)** — it powers *and* reads that node,
so node B just needs a battery pack. The ESP32-S3 enumerates as `/dev/ttyACM*`:
```bash
ls /dev/ttyACM*                 # usually /dev/ttyACM0
screen /dev/ttyACM0 115200      # quit: Ctrl-A then K   (or: minicom -D /dev/ttyACM0 -b 115200)
# no screen? ->  stty -F /dev/ttyACM0 115200 && cat /dev/ttyACM0
```
Read-only, so no PlatformIO needed. The `PAIR` line prints on every clap — keep it
open and clap. (Optional: the uConsole SDR can watch 915 MHz to confirm packets.)

## If it misbehaves
- **Never reaches green:** not enough sky, or GPS still cold — give it longer /
  move to clearer sky. Yellow-blink = it's trying (has sats, not locked).
- **Blue flashes but never CYAN/MAGENTA:** the two aren't hearing each other over
  LoRa (range/antenna) or the claps land >700 ms apart (clap once, sharply).
- **Δt wildly off / not repeatable:** note it and send me the serial — could be
  PPS wiring on one node or a fix that hasn't settled.
- **`pio monitor` throws a termios error:** that was my headless environment; on
  your real terminal it works. If not, tell me and I'll read it remotely.

## After it passes
Design the PCB (two-GPIO RF switch, real BUSY, GPIO48 RGB, mic L/R→GND baked in),
then scale to the 5-node layout.

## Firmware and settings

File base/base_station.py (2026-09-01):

#!/usr/bin/env python3
"""
Base station (Stage 6) — runs on the Raspberry Pi.

Reads Report lines from the base/office ESP32 over USB serial (the lines Stage 5
prints: "RPT node=.. seq=.. onset_us=.. lat=.. lon=.. peak=.. rssi=.."),
correlates reports of the same event, multilaterates the source via TDoA, and
serves a live Leaflet/OpenStreetMap page.

Run:  python3 base_station.py --port /dev/ttyACM0
Deps: numpy scipy pyserial flask   (pip install -r requirements.txt)
"""
import argparse, re, threading, time, math
from collections import deque
import numpy as np
from scipy.optimize import least_squares

C_SOUND = 343.0          # m/s (adjust for temperature: 331 + 0.6*Tc)
EVENT_WINDOW_US = 600_000  # reports within this span = same event (~max propagation)

# ----------------------------------------------------------------------------
# Geo helpers (local equirectangular around a reference)
# ----------------------------------------------------------------------------
R_EARTH = 6_371_000.0

def latlon_to_m(lat, lon, lat0, lon0):
    x = math.radians(lon - lon0) * R_EARTH * math.cos(math.radians(lat0))
    y = math.radians(lat - lat0) * R_EARTH
    return x, y

def m_to_latlon(x, y, lat0, lon0):
    lat = lat0 + math.degrees(y / R_EARTH)
    lon = lon0 + math.degrees(x / (R_EARTH * math.cos(math.radians(lat0))))
    return lat, lon

# ----------------------------------------------------------------------------
# TDoA multilateration
#   nodes: list of (lat, lon);  times_us: onset µs (same order); >=3 required
#   returns (lat, lon, residual_rms_m)
# ----------------------------------------------------------------------------
def solve_tdoa(nodes, times_us, c=C_SOUND):
    n = len(nodes)
    if n < 3:
        return None
    lat0 = sum(a for a, _ in nodes) / n
    lon0 = sum(b for _, b in nodes) / n
    P = np.array([latlon_to_m(a, b, lat0, lon0) for a, b in nodes])   # (n,2) meters
    t = np.array(times_us, dtype=float) * 1e-6                        # seconds
    ref = int(np.argmin(t))                                          # earliest arrival
    obs = c * (t - t[ref])            # observed range-differences, METERS (well-scaled)

    def resid(s):
        d = np.sqrt(((P - s) ** 2).sum(axis=1))                      # source->node dists
        return (d - d[ref]) - obs                                   # residual in meters

    # grid-search seed over the node bounding box (+margin) to dodge local minima,
    # then Levenberg-Marquardt refine. (Residuals in meters => solver converges.)
    xmin, ymin = P.min(axis=0)
    xmax, ymax = P.max(axis=0)
    mx = 0.5 * (xmax - xmin) + 10.0
    my = 0.5 * (ymax - ymin) + 10.0
    gx = np.linspace(xmin - mx, xmax + mx, 30)
    gy = np.linspace(ymin - my, ymax + my, 30)
    best, best_cost = P.mean(axis=0), 1e18
    for x in gx:
        for y in gy:
            r = resid(np.array([x, y]))
            cost = float((r * r).sum())
            if cost < best_cost:
                best_cost, best = cost, (x, y)

    res = least_squares(resid, np.array(best, dtype=float), method="lm")
    lat, lon = m_to_latlon(res.x[0], res.x[1], lat0, lon0)
    rms_m = float(np.sqrt(np.mean(res.fun ** 2)))                   # residual already meters
    return lat, lon, rms_m

# ----------------------------------------------------------------------------
# State (shared with web thread)
# ----------------------------------------------------------------------------
class State:
    def __init__(self):
        self.lock = threading.Lock()
        self.nodes = {}          # node_id -> {lat, lon, n}  (position, averaged)
        self.buffer = deque(maxlen=200)   # recent reports for correlation
        self.events = deque(maxlen=100)   # solved events

    def add_node_pos(self, nid, lat, lon):
        if lat == 0 and lon == 0:
            return
        with self.lock:
            nd = self.nodes.setdefault(nid, {"lat": lat, "lon": lon, "n": 0})
            nd["n"] += 1
            k = nd["n"]
            nd["lat"] += (lat - nd["lat"]) / k     # running average
            nd["lon"] += (lon - nd["lon"]) / k

    def add_report(self, rpt):
        with self.lock:
            self.buffer.append(rpt)
            grp = [r for r in self.buffer
                   if abs(r["onset_us"] - rpt["onset_us"]) <= EVENT_WINDOW_US]
            by_node = {}
            for r in grp:                          # one (latest) per node
                by_node[r["node_id"]] = r
            if len(by_node) < 3:
                return
            nodes, times = [], []
            for r in by_node.values():
                pos = self.nodes.get(r["node_id"])
                if not pos:
                    return
                nodes.append((pos["lat"], pos["lon"]))
                times.append(r["onset_us"])
        sol = solve_tdoa(nodes, times)
        if sol:
            lat, lon, rms = sol
            with self.lock:
                self.events.append({
                    "lat": lat, "lon": lon, "rms_m": rms,
                    "n_nodes": len(nodes), "t": time.time(),
                })
            print(f"[EVENT] {lat:.6f},{lon:.6f}  residual={rms:.1f} m  ({len(nodes)} nodes)")

    def snapshot(self):
        with self.lock:
            return {
                "nodes": [{"id": k, "lat": v["lat"], "lon": v["lon"]}
                          for k, v in self.nodes.items()],
                "events": list(self.events)[-20:],
            }

STATE = State()

# ----------------------------------------------------------------------------
# Serial reader
# ----------------------------------------------------------------------------
RPT_RE = re.compile(
    r"RPT node=(\d+) seq=(\d+) onset_us=(\d+) lat=(-?\d+) lon=(-?\d+) peak=(-?\d+)")

def serial_loop(port, baud):
    import serial
    while True:
        try:
            with serial.Serial(port, baud, timeout=1) as ser:
                print(f"[serial] connected {port} @ {baud}")
                for raw in ser:
                    line = raw.decode(errors="replace").strip()
                    m = RPT_RE.search(line)
                    if not m:
                        continue
                    nid, seq, onset, lat_i, lon_i, peak = (int(x) for x in m.groups())
                    lat, lon = lat_i / 1e7, lon_i / 1e7
                    STATE.add_node_pos(nid, lat, lon)
                    STATE.add_report({"node_id": nid, "seq": seq,
                                      "onset_us": onset, "peak": peak})
        except Exception as e:
            print(f"[serial] {e}; retry in 3s")
            time.sleep(3)

# ----------------------------------------------------------------------------
# Web (Flask + Leaflet)
# ----------------------------------------------------------------------------
MAP_HTML = """<!doctype html><html><head><meta charset=utf-8>
<title>Acoustic Triangulation</title>
<link rel=stylesheet href="https://unpkg.com/leaflet@1.9.4/dist/leaflet.css"/>
<script src="https://unpkg.com/leaflet@1.9.4/dist/leaflet.js"></script>
<style>html,body,#map{height:100%;margin:0}</style></head><body>
<div id=map></div><script>
var map=L.map('map'); L.tileLayer('https://{s}.tile.openstreetmap.org/{z}/{x}/{y}.png',
 {maxZoom:19,attribution:'OSM'}).addTo(map);
var nodeLayer=L.layerGroup().addTo(map), evLayer=L.layerGroup().addTo(map), fitted=false;
async function tick(){
 let s=await (await fetch('/api/state')).json();
 nodeLayer.clearLayers(); evLayer.clearLayers(); let pts=[];
 for(const n of s.nodes){L.circleMarker([n.lat,n.lon],{radius:7,color:'#1565c0',
   fillColor:'#42a5f5',fillOpacity:1}).bindTooltip('node '+n.id,{permanent:true}).addTo(nodeLayer);
   pts.push([n.lat,n.lon]);}
 for(const e of s.events){L.circle([e.lat,e.lon],{radius:Math.max(e.rms_m,3),
   color:'#c62828',fillColor:'#ef5350',fillOpacity:.4}).bindPopup(
   'source ±'+e.rms_m.toFixed(1)+'m ('+e.n_nodes+' nodes)').addTo(evLayer);
   pts.push([e.lat,e.lon]);}
 if(!fitted && pts.length){map.fitBounds(pts,{padding:[40,40],maxZoom:19});fitted=true;}
}
setInterval(tick,1000); tick();
</script></body></html>"""

def run_web(host, port):
    from flask import Flask, jsonify, Response
    app = Flask(__name__)
    app.route("/")(lambda: Response(MAP_HTML, mimetype="text/html"))
    app.route("/api/state")(lambda: jsonify(STATE.snapshot()))
    app.run(host=host, port=port, threaded=True)

# ----------------------------------------------------------------------------
if __name__ == "__main__":
    ap = argparse.ArgumentParser()
    ap.add_argument("--port", default="/dev/ttyACM0", help="base ESP32 serial port")
    ap.add_argument("--baud", type=int, default=115200)
    ap.add_argument("--web-host", default="0.0.0.0")
    ap.add_argument("--web-port", type=int, default=8080)
    a = ap.parse_args()
    threading.Thread(target=serial_loop, args=(a.port, a.baud), daemon=True).start()
    print(f"[web] http://localhost:{a.web_port}")
    run_web(a.web_host, a.web_port)

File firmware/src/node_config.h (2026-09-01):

#pragma once
#include <stdint.h>

// ---- Node identity (change per node: 1..5) ----
// Overridable per-board via a build flag (-D NODE_ID=2), e.g. the twonode_b env.
#ifndef NODE_ID
#define NODE_ID        1
#endif

// ---- Audio ----
#define SAMPLE_RATE    16000        // Hz (onset timing + basic classify)
// Onset must clear BOTH an adaptive 8x-noise-floor gate AND this absolute floor,
// so a very quiet room can't drop the floor low enough to trigger on nothing.
// Units = |sample| after >>8 (24-bit). A close clap ~ several million; ambient
// well under this. Lower it if distant real events are being missed.
#ifndef ONSET_ABS_MIN
#define ONSET_ABS_MIN  120000
#endif

// ============================================================
//  Pin map — ESP32-S3-Zero  (avoids strapping / USB / LED pins)
//  See NODE_FIRMWARE_DESIGN.md
// ============================================================

// I2S mic (INMP441)   —  L/R pin tied to GND (left channel)
#define PIN_I2S_BCLK   4
#define PIN_I2S_WS     5
#define PIN_I2S_SD     6

// SPI to the LoRa (shared by all radio modules).  Pin ORDER matches the RYLR689
// carrier-PCB pad layout: MISO/MOSI/SCK/NSS come out of the ESP right-hand header
// column in the same left-to-right order as the module pads, so the SPI bus routes
// with ZERO jumpers.  (MOSI<->SCK swapped vs the old breadboard map for this.)
#define PIN_LORA_SCK   11           // was 12
#define PIN_LORA_MISO  13
#define PIN_LORA_MOSI  12           // was 11
#define PIN_LORA_NSS   10
#define PIN_LORA_RST   44           // was 7 (NRST -> GP44 so GP7 can carry BUSY as copper)
#define PIN_LORA_DIO0  9            // SX127x-only (SX1276 fleet); unused on SX126x/PCB

// GPS (ATGM336H)  — we only READ it (GPS TX -> ESP, plus PPS)
#define PIN_GPS_RX     1            // ESP32 RX  <-  GPS TX (NMEA in)
#define PIN_GPS_TX     43           // unused spare (GPS RX pin left open)
#define PIN_PPS        2            // was 8  (GP8 freed for the LoRa RF-switch)

// ---- LoRa MODULE select (pick ONE; every board in a test must match) ----
//   XL1276-P01 -> SX1276  (SX127x, DIO0)         [default, 915, the fleet part]
//   RYLR689    -> LLCC68  (SX126x, DIO1 + BUSY)  [915, for the A/B comparison]
//   433 test   -> SX1278  (SX127x, DIO0)         [433 only]
// Override per build with -D LORA_MOD_LLCC68 etc, or just edit these three lines:
#if !defined(LORA_MOD_SX1276) && !defined(LORA_MOD_LLCC68) && !defined(LORA_MOD_SX1278_433)
  #define LORA_MOD_SX1276           // default
#endif

#if defined(LORA_MOD_LLCC68)
  #define LORA_FAMILY_SX126X        // uses DIO1 + BUSY; radio class in lora_radio.h
  #define LORA_FREQ   915.0f
  #define LORA_TCXO_V 0.0f          // RYLR689 has a 32 MHz CRYSTAL, not a TCXO -> 0.0
  #define LORA_RFSW_MANUAL          // RYLR689 breaks out RFSW_V1/V2: host must drive them
#elif defined(LORA_MOD_SX1278_433)
  #define LORA_CHIP  SX1278
  #define LORA_FREQ  433.0f
#else
  #define LORA_CHIP  SX1276
  #define LORA_FREQ  915.0f
#endif

// ---- SX126x-only pins (LLCC68 / RYLR689 — the carrier PCB) -----------------
// Repinned for the carrier PCB so the module's NEAR row (the SPI + RF-switch pads
// that face the ESP) all land on the ESP RIGHT header column -> clean 2-layer
// copper, zero jumpers. Only the two signals on the module's FAR row (BUSY, DIO1)
// need a short flying wire, because they sit on the antenna edge, physically
// opposite the ESP. RF-switch MUST be driven or the radio can't TX or RX.
//   RFSW_V1 -> GP9   RFSW_V2 -> GP8   (module pins 9/8, ESP right column; each ESP
//   NRST    -> GP7   (module left-end pad, clean)
//   FAR-row signals routed as BOTTOM COPPER (LoRa pads are through-holes), each
//   entering the under-module space from OPPOSITE sides so they never cross ->
//   ZERO jumper wires. Pins chosen for that: DIO1 from the left, BUSY from the right.
//   DIO1 -> GP3  (left col, above the 3V3 rail -> under module from the LEFT)
//   BUSY -> GP7  (top of left col        -> around the right -> from the RIGHT)
//   NRST -> GP44 (moved here; routes as top copper to the near-row pad)
#define PIN_LORA_DIO1   3
#ifndef PIN_LORA_BUSY
#define PIN_LORA_BUSY   7           // was 44
#endif
#define PIN_LORA_RFSW1  9           // RFSW_V1 (module pin 9) -> ESP GP9 (routes to outer RFV1 pad)
#ifndef PIN_LORA_RFSW2
#define PIN_LORA_RFSW2  8           // RFSW_V2 (module pin 8) -> ESP GP8 (clean, inner RFV2 pad)
#endif
#ifndef LORA_TCXO_V
#define LORA_TCXO_V     0.0f        // (only the SX126x path reads this)
#endif
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

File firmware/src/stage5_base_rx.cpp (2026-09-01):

// Stage 5 — base receiver + 2-node sync check (M2, the make-or-break)
//
// Receives Reports over LoRa, prints each as a parseable line (for the Pi in
// Stage 6), and when two nodes report the SAME event prints their Δt and the
// implied distance difference (Δt × 343 m/s).
//
//   pio run -e stage5 -t upload -t monitor
//
// M2 TEST: 2 nodes a known distance apart, clap between them, check
// Δt ≈ (dist_to_A − dist_to_B) / 343 m/s.

#include <Arduino.h>
#include <RadioLib.h>
#include <SPI.h>
#include "node_config.h"
#include "report_packet.h"

#include "lora_radio.h"

volatile bool rxFlag = false;
void IRAM_ATTR onRx() { rxFlag = true; }

#define NREC 16
static Report   recent[NREC];
static uint32_t rec_ms[NREC];
static int      rec_i = 0;

#define USPERDAY   86400000000LL
#define PAIR_US    600000LL        // same-event onset window (µs)
#define PAIR_AGE   3000            // and reports must arrive within 3 s (ms)

static uint16_t last_seq_node[64];
static bool     seen_node[64];

static int64_t wrap_us(int64_t dt) {                 // handle µs-of-day midnight wrap
  if (dt >  USPERDAY / 2) dt -= USPERDAY;
  if (dt < -USPERDAY / 2) dt += USPERDAY;
  return dt;
}

static void consider_pair(const Report& r, uint32_t now_ms) {
  for (int k = 0; k < NREC; k++) {
    if (rec_ms[k] == 0) continue;
    if (now_ms - rec_ms[k] > PAIR_AGE) continue;     // must be recent arrivals
    const Report& o = recent[k];
    if (o.node_id == r.node_id) continue;
    int64_t dt = wrap_us((int64_t)r.onset_gps_us - (int64_t)o.onset_gps_us);
    if (dt < -PAIR_US || dt > PAIR_US) continue;     // same event only
    double dd = (double)dt * 1e-6 * 343.0;
    Serial.printf("   PAIR nodes %d/%d  dt=%lld us  -> Δdist=%.2f m\n",
                  r.node_id, o.node_id, (long long)dt, dd);
  }
}

void setup() {
  Serial.begin(115200);
  delay(400);
  Serial.println("\n== Stage 5: base receiver + sync check ==");
  SPI.begin(PIN_LORA_SCK, PIN_LORA_MISO, PIN_LORA_MOSI, PIN_LORA_NSS);
  int st = lora_begin();
  if (st != RADIOLIB_ERR_NONE) { Serial.printf("LoRa init FAILED %d\n", st); while (1) delay(1000); }
  radio.setPacketReceivedAction(onRx);
  radio.startReceive();
  Serial.println("Listening for node reports...");
}

void loop() {
  if (!rxFlag) return;
  rxFlag = false;

  Report r;
  int st = radio.readData((uint8_t*)&r, sizeof(Report));
  float rssi = radio.getRSSI();          // cache BEFORE re-arming (last-packet RSSI)
  radio.startReceive();
  if (st != RADIOLIB_ERR_NONE) return;
  if (r.node_id >= 64) return;

  // dedupe repeats of the same (node_id, seq)
  if (seen_node[r.node_id] && last_seq_node[r.node_id] == r.seq) return;
  seen_node[r.node_id] = true; last_seq_node[r.node_id] = r.seq;

  uint32_t now_ms = millis();
  Serial.printf("RPT node=%d seq=%u onset_us=%llu lat=%d lon=%d peak=%d rssi=%.1f\n",
                r.node_id, r.seq, (unsigned long long)r.onset_gps_us,
                r.lat_1e7, r.lon_1e7, r.peak, rssi);

  consider_pair(r, now_ms);
  recent[rec_i] = r; rec_ms[rec_i] = now_ms; rec_i = (rec_i + 1) % NREC;
}

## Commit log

2026-09-01 v1: acoustic node carrier PCB — DRC-clean 2-layer milled design
    - 56x53mm, 0 crossings, 0 jumper wires, GND pour, rounded corners, USB-C + ANT notches
    - All footprints verified vs real parts incl. RYLR689 datasheet pin map
    - Power: MCP1700 LDO (correct GND|VIN|VOUT), Cin/Cout 0805, C1 10uF at LoRa VDD,
    C2 470uF low-ESR buffer, JP1 0805 ferrite (via-in-pad) isolating ESP+LoRa
    - Firmware pins match (14/14); sourced BOM with Amazon links in inspection PDF
    - Full DRC pass: shorts, clearances, containment, body-collision, net continuity
    [node-B_Cu.gbl, node-Edge_Cuts.gko, node-F_Cu.gtl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]
2026-09-01 v2: RF antenna-feed ground keepout
    - Clear the bottom GND pour in a rectangle around ANT (pin10) + ANT_PAD (pin12), the
    RYLR689's 50-ohm RF output, so the pour doesn't add shunt capacitance / detune the
    coil antenna. Left edge stays right of LGND (pin13) so grounds are untouched.
    - Confirmed only ANT/ANT_PAD sit inside the keepout (no stranded GND, no bottom signal
    through it); added a permanent drc.py check for it.
    - Rendered on preview / two-sides (bottom) / placement; noted in the inspection PDF
    fab steps and fab_guide.md. Version stamp VERSION='v2' on renders + PDF.
    - Full DRC still ALL PASS.
2026-09-01 v2.1: widen 3V3 column-crossing isolation 0.22 -> 0.32 mm
    - Thin the one column-crossing trace 0.6 -> 0.4mm (carries ~200mA; 0.4mm is ~3x margin)
    so its isolation (0.32mm) matches the LoRa 1.27mm web floor (0.37mm) instead of being
    the tightest spot on the board. Added gerber aperture D25 (0.4mm).
    - Refresh fab_guide.md milling params to the real design: fine V-bit REQUIRED, drills
    0.6/0.8/1.0/3.2, M3 corners = registration (removed stale 3.0mm dowel workflow).
    [node-B_Cu.gbl, node-F_Cu.gtl]
2026-09-01 v2.2: 3018-friendly - uniform 0.47mm isolation, constant-Z millable (no height map)
    Target: a no-surface-mapping 3018 milling at constant Z. Open every fine gap to a
    single 0.47mm floor (set by the unavoidable LoRa 1.27mm pitch) so nothing is tighter:
    - LoRa pads 0.9->0.8mm, hole 0.6->0.5mm => web 0.37->0.47mm, ring 0.15mm
    - ESP pads 1.5->1.3mm, hole 1.0->0.8mm => ring 0.25mm; opens all ESP-adjacent gaps
    - crossing trace 0.4->0.3mm => crossing isolation 0.32->0.47mm
    - JP1 via 0.6->0.5mm (folds into the LoRa drill; drill set stays 4: 0.5/0.8/1.0/3.2)
    Result: GLOBAL min pad-pad AND trace-trace both = 0.470mm. DRC ALL PASS, 14/14 pins
    match, 3V3/GND/BAT continuity intact, RF kee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
    [node-B_Cu.gbl, node-F_Cu.gtl, node.drl]
2026-09-06 Remove PlatformIO build artifacts from repo; update .gitignore
    firmware/.pio/ was accidentally tracked — removes 10,944 compiled
    object files, dependency caches, and toolchain output. Added .pio/,
    firmware/.pio/, and common KiCad caches to .gitignore.
2026-09-06 Add POWER.md: current draw, solar sizing, battery autonomy, DS3231 holdover
    Per-subsystem current table (GPS is the dominant 30 mA draw), daily energy
    calc (4.6 Wh), panel sizing math (3.7× margin with 5W), battery autonomy
    table (1-5 days depending on cell count), full power chain diagram, and
    Appendix A: DS3231 TCXO holdover variant that halves draw to ~30 mA.
2026-09-06 Add SX1276 (XL1276-P01) variant: PCB v3, JLCPCB gerbers, updated docs
    - pcb/gen_pcb_sx1276.py: new PCB generator for XL1276-P01/SX1276.
    56×53 mm, 2-layer FR4, 7-layer gerber set for JLCPCB manufacturing.
    3 fewer control pins vs RYLR689 (no RFSW1/V2, no BUSY). GP7+GP8 freed.
    XL1276-P01 castellation footprint (Ra-01S compatible, 2mm pitch, 16×16mm).
    - pcb/out_sx1276/: generated gerbers (F_Cu, B_Cu, F_Mask, B_Mask, F_Silk,
    Edge_Cuts, drill) ready to finish in KiCad (add GND pour) then order.
    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
    [node_sx1276-B_Cu.gbl, node_sx1276-B_Mask.gbs, node_sx1276-Edge_Cuts.gko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]
2026-09-06 fix(pcb): correct XL1276-P01 pinout — DIO0 is right col, not left
    Two critical errors discovered during double-check pass:
    1. XL1276-P01 pinout was wrong. The module is NOT Ra-01S-compatible:
    - Old (wrong): left col has DIO0 at bottom; right col: NC/VCC/NSS/SCK/MOSI/MISO/RST/GND
    - Actual: left col: ANT/GND/GND/DIO1-5; right col: GND/VCC/DIO0/RST/SCK/MISO/MOSI/NSS
    - DIO0 is on the RIGHT column (pin 11), 3rd from top
    2. DIO0 routing was completely wrong (routed to left col y=30 via long bottom-layer
    detour). Replaced with: B_Cu from G9 → via at (46,40), then short F_Cu stub
    to LDIO0 at (44,40). All SPI routes auto-corrected via name-based lookup.
    ESP32-S3-Zero column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
    [node_sx1276-B_Cu.gbl, node_sx1276-B_Mask.gbs, node_sx1276-F_Cu.gtl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]
2026-09-07 docs: mark SX1276 v3 PCB as separate untested variant
    README now shows a variants table: v2 RYLR689 (tested) vs v3 SX1276 (untested).
    BOM_sx1276.md and fab_guide_sx1276.md both carry a top-level UNTESTED warning
    directing builders to BOM.md (RYLR689 v2) if they need a working node today.
    Repo layout section updated to label pcb/ clearly as the untested v3 PCB.
